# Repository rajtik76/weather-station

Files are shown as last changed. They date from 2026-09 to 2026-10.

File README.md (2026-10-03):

# Weather forecast station






Can a balcony weather station forecast its own next six hours better than
assuming nothing changes? A small model, trained on eight years of Czech
Hydrometeorological Institute (ČHMÚ) records, forecasts temperature and the
chance of rain one to six hours ahead from the station's own readings alone.
Every forecast is scored against what the station then measured, and the
front page sets the last 30 days' verdict beside the next six hours.

The bar to clear is persistence: the temperature stays as it is. The target
is not the air temperature a weather service forecasts but what this sensor
will read, and it is no professional sensor: on clear mornings the sun heats
its shield and the reading runs more than 10 °C high. A forecast for Plzeň
knows nothing of that, so it is no yardstick here. The model has to learn
this balcony, morning sun included, and the score shows how far the station
correction gets it: every forecast is also scored as the base model gave it,
before the correction.

The verdict is given for six hours ahead, with every shorter horizon beside
it, in three numbers over the last 30 days:

- **skill** - how much smaller the forecast's miss was than persistence's; below zero the forecast did worse
- **mean miss** - in °C, beside persistence's
- **in range** - how often the reading landed inside the forecast range; the range is drawn to hold 80 %, so less means too narrow

Until a day of forecasts has come true, the verdict says it is too early.

Running at [weather.rajtik.com](https://weather.rajtik.com).

## Architecture

```
SHT4x    --I2C--+
VEML7700 --I2C--+
BMP280   --I2C--+--> ESP32 --HTTPS--> Laravel API --> PostgreSQL
INMP441  --I2S--+                       |    |
                                        |  forecast service (Python)
                                   Livewire pages
```

- SHT4x (temperature, humidity) and VEML7700 (light) outside in a passive radiation shield, BMP280 (pressure) indoors, INMP441 microphone in the shield
- Readings every 30 s, folded into ten-minute windows and uploaded to the API
- Rain is detected from the microphone spectrum
- A Python service forecasts after every upload from the station's last 56 hours, with a station correction fitted daily on the last 60 days

## Known limitations

- Sensor reads more than 10 °C above air temperature for an hour or two on clear mornings (sun on the east-facing balcony, shield only partly helps); accepted, the forecast is scored against these same readings
- VEML7700 sits behind the shield's louvers: the shape of the day is real, the lux do not compare with a station in the open
- Rain thresholds come from one rain (checked against the ČHMÚ gauge 3.5 km away) and belong to this mounting; drizzle too fine to drip is not heard

## Run it

Needs PHP 8.4, Node 24 and Docker.

```
docker compose up -d              # PostgreSQL, with a second database for the tests
composer setup                    # install, .env, app key, migrate, build assets
php artisan migrate:fresh --seed  # a month of sample data; wipes the local database
composer dev                      # server, queue worker, logs, vite
```

## Documentation

- [`docs/development.md`](docs/development.md) - layout, configuration, tests, deploying
- [`docs/api.md`](docs/api.md) - ingest endpoint and storage
- [`docs/scoring.md`](docs/scoring.md) - how the forecast is scored
- [`firmware/README.md`](firmware/README.md) - wiring, protocol, hardware notes; [`firmware/CHANGELOG.md`](firmware/CHANGELOG.md)
- [`forecast/README.md`](forecast/README.md) - model and service; [`forecast/CHANGELOG.md`](forecast/CHANGELOG.md)
- `docs/hardware/kicad/` - KiCad projects of the station and the shield hub

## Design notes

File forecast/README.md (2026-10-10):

# Forecast

Temperature, humidity and pressure 1 to 6 hours ahead, and the chance of rain within those hours, from the station's own readings alone (no neighbouring stations, no numerical weather model, no radar at forecast time). Model history: [`CHANGELOG.md`](CHANGELOG.md).

## How it works

### Training data

- ČHMÚ open data (CC BY 4.0, credited in the site footer and on the forecast page): 10-minute records of the professional ("20000" series) stations, 2018 to 2025, the 32 below 700 m; about 1.7 million hourly examples
- Measures temperature, humidity, station pressure, plus precipitation (training label only)

### Inputs

`features.py`, shared by training and the service:

- Current temperature and humidity, and their distance from the dew point
- Change of temperature, humidity and pressure over 1, 3, 6, 12, 24, 48 h
- Pressure position in its two-day swing
- Unsettledness of the last 3 h: jitter of temperature and humidity, whether the pressure fall is speeding up
- Rain in the last 1 h and 3 h
- Solar time of day, day of the year
- Pressure only as a change (its level encodes elevation)
- Jitter computed on readings rounded to ČHMÚ's resolution

### Models

`train.py`: scikit-learn `HistGradientBoosting`, per horizon.

- Temperature, humidity, pressure: three quantile models (10th, 50th, 90th percentile of the change); the range should hold 4 readings in 5
- Rain: classifier for at least 0.1 mm within the next n hours
- Rain inputs hidden on 30 % of training rows (the balcony may have no rain source)
- `nest_rain()` in `forecast.py` caps the 1 h rain chance by the 2 h one (alone it gave 50-100 % on dry balcony days while longer horizons said 1-10 %)

### Station correction

`correction.py`; `POST /correction` fits it, Laravel caches the answer for a day and sends it back with every forecast.

- The service forecasts the station's recent history and compares it with what was measured
- Per variable and horizon, a ridge regression of the error on solar time and on the errors just verified
- Range widened or narrowed to hold 80 % of the station's readings
- Solar time as bins: 20 minutes from 5 to 12 h, an hour elsewhere
- Applies to temperature and humidity; correcting pressure scored worse
- The answer also carries the forecast before the correction (`base`)

### Light experiment

`sun_correction.py` (light-v5) learns the base model's misses on the balcony by day, `sky_gate.py` (light-v6) scales light-v5's shift by the sky the VEML7700 reads, `trees.py` carries the fitted models as plain numbers; `POST /light-correction` fits both once a day, `POST /light-forecast` issues both. Both enter the model race that picks the shown temperature per part of the day ([`docs/scoring.md`](../docs/scoring.md#model-race)).

- Per horizon a gradient-boosting model of the base forecast's miss with an absolute loss (the median miss, as the page scores the mean absolute miss)
- Sun on the shield from the temperature swing within each 10-minute window (`temperature_max - temperature_min`, smoothed over 30 min, peak of the hour, slow mean); reported since the shield went up, so every day from `since` on teaches, also those before the VEML7700
- Also the sun's position at issue and at the target (on the east facade or not), the change of the last 1 and 3 h, the base model's own change and its misses verified now (1 h ahead and the same horizon)
- Night stays the base forecast: sun lower than 3° below the horizon at issue and at the target
- Band: the base band moved with the median, widened to hold 4 readings in 5 by misses of models that did not see that day (four folds by local day)
- light-v5 takes no illuminance: with a week of light it helped some days and hurt others; a window without light is forecast too
- light-v6: a sky score per daylight window (sun above 8°), the illuminance over the brightest reading at the same UTC clock slot in the 14 days before the issue's local day; the state at issue is the mean score of the last hour in daylight, of the daylight in the last 24 h otherwise, overcast below 0.45, clear above 0.8
- light-v6 per horizon and state: a factor, the shift-weighted median of the miss over light-v5's out-of-fold shift (0 to 1.5, from 40 training rows); an unknown state or one without a factor keeps light-v5; its band is widened by its own out-of-fold misses

### Service

`serve.py`: stateless, no database.

- After every upload (`App\Jobs\ForecastWeather`), Laravel sends the last 56 hours and the cached correction; the answer is stored in `forecasts`
- Once a day Laravel sends the last 60 days to `POST /correction`, with `since` from `FORECAST_HISTORY_SINCE` if set (shield went up 16 September 2026, production learns from the 17th); a `409` for a stale correction refits it at once
- Page shows temperature and rain; humidity and pressure stay in the row
- Last 30 days of forecasts are scored as shown and before the correction, on the same hours, against persistence ([`docs/scoring.md`](../docs/scoring.md))

## Results

Scored on 2025 at four ČHMÚ stations the models never saw (Plzeň-Mikulka, Cheb, Kuchařovice, Pardubice). Mean absolute error, model median / persistence:

| Ahead | Temperature | Humidity | Pressure |
| ----- | --- | --- | --- |
| 1 h | 0.50 / 0.82 °C | 2.7 / 3.6 %  | 0.19 / 0.30 hPa |
| 3 h | 0.94 / 2.09 °C | 4.7 / 8.5 %  | 0.44 / 0.77 hPa |
| 6 h | 1.38 / 3.66 °C | 6.4 / 14.4 % | 0.85 / 1.36 hPa |

- 10-90 % range held the truth 76-81 % of the time
- Rain Brier score vs climatological rate: 0.039 / 0.068 at 1 h, 0.103 / 0.148 at 6 h
- Rain onset (still dry): ROC AUC 0.86 at 1 h, 0.79 at 6 h
- Training on 2018-2020 or 2022-2024 scored the same on 2025

Balcony, correction fitted up to 18 September 2026, scored 19 to 24 September (two weeks of record, will move):

| 6 h ahead | Without correction | With correction |
| --- | --- | --- |
| Temperature | 2.51 °C | 1.82 °C |
| Humidity | 9.7 % | 7.0 % |
| Temperature range coverage | 57 % | 74 % |

Bins vs two harmonics, walked forward day by day, fitted only on readings from 17 September (after the shield), scored 20 to 26 September:

| Case | Bins | Harmonics | No correction |
| --- | --- | --- | --- |
| Temperature 1 h ahead | 0.89 °C | 0.99 °C | 0.92 °C |
| 6 to 11 h, 2 h ahead | 1.74 °C | 2.25 °C | |
| 6 to 11 h, 3 h ahead | 2.03 °C | 2.45 °C | |
| 22 September (shade morning), 3 h ahead | 1.55 °C | 2.82 °C | 0.90 °C |

## Limitations

- A single station sees weather only once it arrives: on 24 September 2026 rain began at 06:20, forecasts issued before gave 1-4 % (air still fairly dry, pressure falling moderately, front invisible from the balcony)
- The correction made that morning worse: it learnt the sun warms the shield after sunrise, the morning was overcast; from temperature alone it cannot tell the two kinds of morning apart
- Sunny mornings are where the correction pays (halves misses of 3-5 °C)

## Running it

Python 3.14 and [uv](https://docs.astral.sh/uv/); run from this directory (`data/` and `models/` are gitignored).

```
uv run fetch_chmi.py download   # ~15 000 CSVs, 3 GB, into data/raw; resumable
uv run fetch_chmi.py build      # one parquet per station, 170 MB, + data/stations.csv
uv run train.py                 # ~22 minutes on an M4, writes models/forecast.joblib
uv run evaluate_balcony.py      # scores it on data/balcony.csv, rain from Mikulka
uv run serve.py                 # the service on :8000
```

- `evaluate_balcony.py` needs `data/balcony.csv` with columns `timestamp,t,h,p` (Unix seconds, °C, %, hPa station pressure) exported from the production database; rain labels (stand-in for the microphone detector) come from the ČHMÚ gauge at Plzeň-Mikulka, 3.5 km away
- Service env: `MODEL_PATH` (default `models/forecast.joblib`), `HOST`, `PORT`; reloads the model when the file changes
- Laravel reaches it through `FORECAST_URL`; unset, no forecasts

### The service's contract

```
POST /correction
{"longitude": 13.40, "since": 1789596000,
 "readings": [{"timestamp": 1790000000, "temperature": 9.7,
               "humidity": 76.0, "pressure": 976.6, "rain": null}, ...]}
```

- Up to a year of readings: °C, %, station pressure in hPa, rain in mm per ten minutes (null or absent without a source)
- `since` optional: the correction learns only from readings from then on; base models still read all (they need 48 h behind every forecast, as do the errors the correction takes as inputs)

```
{"model": "2026-09-24T08:40:43.136429+00:00", "correction": 3,
 "targets": {"T_1h": {"intercept": 0.41,
                      "coefficients": {"solar_0": -0.12, ..., "error_same": 0.3, "error_1h": 0.25},
                      "widen": 0.08}, ...}}
```

- One target per corrected variable and horizon; fewer, or none, while the history is short (3 days) or never verified
- Plain numbers: the ridge regression's intercept and weights by input name, and how far the range is widened (negative: narrowed)

```
POST /forecast
{"longitude": 13.40, "correction": {...},
 "readings": [{"timestamp": 1790000000, ...}, ...]}
```

- Readings as above; 54 h before the latest suffice (48 h behind the forecast issued 6 h earlier, whose verified error the correction reads), Laravel sends 56
- `correction` optional: the `POST /correction` answer as received; without it the forecast is the base models'
- A correction fitted for another model or correction version gets 409; malformed requests get 422 with the reason

```
{"issued_at": 1790000000, "model": "2026-09-24T08:40:43.136429+00:00",
 "corrected": true, "correction": 3,
 "horizons": [{"hours": 1,
               "temperature": {"low": 12.4, "mid": 13.84, "high": 15.56},
               "humidity": {...}, "pressure": {...},
               "rain_probability": 0.023,
               "base": {"temperature": {"low": 12.1, "mid": 13.46, "high": 15.9},
                        "humidity": {...}, "rain_probability": 0.023}}, ...]}
```

- `issued_at`: the latest reading's ten-minute window
- `model`: the bundle's `trained_at`
- `corrected`: whether the correction sent covered every corrected target
- `correction`: version of the correction logic (`CORRECTION_VERSION` in `correction.py`, raised with every change, logged in the changelog)
- `base`: forecast before the correction, for the two corrected variables; pressure is not corrected, so its forecast is the one above
- `base.rain_probability`: the classifier's value before `nest_rain()` capped the first hour; a capped run shows as `data->0->'base'->>'rain_probability'` above `data->0->>'rain_probability'`
- `GET /health` answers `{"status": "ok", "model": ..., "correction": 3, "experiment": "light-v6"}`

```
POST /base
{"longitude": 13.40, "since": 1789400000, "readings": [...]}
```

Base forecast for every reading from `since` on, for forecasts stored before the service returned `base`:

```
{"model": "2026-09-24T08:40:43.136429+00:00",
 "forecasts": [{"issued_at": 1789400000,
                "horizons": [{"hours": 1, "temperature": {...},
                              "humidity": {...}, "rain_probability": 0.023}, ...]}, ...]}
```

- Base models look 48 h back only, so the answer equals what the service gave at the time if readings start that far before `since`; the correction is not recomputed
- `php artisan forecast:backfill-base` asks a week at a time, with three days of readings before it, and fills in only forecasts made by the model now running

```
POST /light-correction
{"longitude": 13.40, "since": 1789596000,
 "readings": [{"timestamp": 1790000000, "temperature": 9.7, "humidity": 76.0, "pressure": 976.6,
               "temperature_min": 9.62, "temperature_max": 9.81,
               "illuminance": 1830.5, "received_at": 1790000031}, ...]}
```

- Readings as for `/correction` plus `temperature_min` and `temperature_max` (°C within the window, null without) and `illuminance` (lx, null without); `received_at`, which Laravel sends too, is ignored
- `since` optional: only forecasts issued from then on teach it (Laravel sends `FORECAST_HISTORY_SINCE`)

```
{"model": "2026-09-24T08:40:43.136429+00:00", "version": "light-v6",
 "fit": {"day": "2026-10-07",
         "horizons": [{"hours": 1, "baseline": 0.31, "widen": 0.42,
                       "trees": [[[6, 0.83, 0, 1, 2], [0.12], [-0.05]], ...]}, ...],
         "gate": {"envelope": [null, ..., 2431.5, ...],
                  "horizons": [{"hours": 1, "factors": {"day:overcast": 0.24, "night:clear": 1.5}, "widen": 0.44}, ...]}}}
```

- `day`: the newest reading's local day
- One entry per horizon with 300 verified daytime rows; fewer or none while the history is short
- `trees`: the fitted model as plain numbers, per tree its nodes; a split `[input, threshold, missing values go left (0/1), left, right]` (inputs in `sun_correction.INPUTS` order, threshold null for +inf), a leaf `[value]`; the miss is `baseline` plus one leaf per tree
- `gate`: light-v6 on top; `envelope` the brightest illuminance per UTC 10-minute clock slot (144) in the 14 days before `day`, null where never lit; per horizon its factors by state (`day:` or `night:` and `overcast`, `mixed` or `clear`) and its own `widen`
- About 200 KB; Laravel caches it per sensor, local day and `since`, and fits it on readings through the newest of the window it issues from

```
POST /light-forecast
{"longitude": 13.40, "experiment": {...}, "readings": [...]}
```

- `experiment`: the `/light-correction` answer as received; another model or version, or a fit for another local day than the newest reading's, gets 409; a malformed tree or gate 422
- Readings as for `/light-correction`; 54 h suffice, as for `/forecast`

```
{"issued_at": 1790000000, "model": "2026-09-24T08:40:43.136429+00:00", "version": "light-v6",
 "versions": {"light-v5": [{"hours": 1, "temperature": {"low": 12.4, "mid": 13.6, "high": 15.1}}, ...],
              "light-v6": [{"hours": 1, "temperature": {"low": 11.9, "mid": 12.7, "high": 14.0}}, ...]}}
```

- Per version one horizon per fitted horizon; at night the base band; `version` names the newest
- `php artisan forecast:backfill-light <Y-m-d>` replays both calls for forecasts stored without the version `/health` reports (`experiment`), each from the readings the server held at the time; an older version is replaced where the current one is issued, a forecast it cannot issue keeps the older one; every version answered joins the race candidates

## Deploying

- `Dockerfile` builds from this directory: dependencies into a virtualenv with uv, then Python, the virtualenv and the eight service files; about 550 MB
- The model is not in the image: mounted at `/models`
- No domain or published port; Laravel reaches it on the internal Docker network
- New model: train, check `evaluate_balcony.py`, copy `forecast.joblib` over the mounted one, add a changelog entry
- First deploy of a service that returns `base`: run `php artisan forecast:backfill-base` in the app container before a new model goes on (only the model that made a forecast can recompute its base)

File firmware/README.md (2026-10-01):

# Firmware

ESP32-WROOM-32, mains powered, never sleeps.

- Every 30 s: temperature and humidity (SHT4x), pressure (BMP280), illuminance (VEML7700)
- Continuously: INMP441 microphone
- Ten-minute windows: mean, min, max per channel plus noise levels and third-octave spectrum
- Each closed window is uploaded to `POST /api/v1/measurement` over HTTPS; failures stay buffered on flash
- Station is inspectable over the LAN without a cable

```
SHT4x    --I2C--+
VEML7700 --I2C--+
BMP280   --I2C--+--> ESP32-WROOM-32 --HTTPS--> Laravel API
INMP441  --I2S--+     core 0: noise   |    \
                      core 1: the rest |     HTTP on the LAN: status and log
                                       |
                         window buffer on the flash, 144 entries (a day)
```

## Hardware

Schematics (KiCad exports): [station](../docs/hardware/kicad/WeatherStation/WeatherStation_schematic.svg), [base board](../docs/hardware/kicad/BaseBoard/BaseBoard_schematic.svg), [shield hub](../docs/hardware/kicad/ShieldHub/ShieldHub_schematic.svg).

### Cable

4 m FTP (four twisted pairs) from ESP32 board to shield hub. ESP32 side: Dupont pins. Hub side: soldered in column 5 of the perfboard.

| Pair | Wire | Signal | ESP32 side | Hub side |
| ---- | --- | --- | --- | --- |
| 1 | blue | SD | GPIO33 (D33) | R5 47 Ω → mic SD  |
| 1 | white-blue | GND | GND | GND, C2 |
| 2 | orange | SDA | GPIO21 (D21) | SHT4x, VEML7700 |
| 2 | white-orange | 3V3 | 3V3 | C2, all three VCC |
| 3 | white-green  | SCL | GPIO22 (D22) | SHT4x, VEML7700 |
| 3 | green | GND | GND | GND |
| 4 | white-brown  | SCK | GPIO26 via R3 47 Ω | mic SCK |
| 4 | brown | WS | GPIO25 via R4 47 Ω | mic WS |

- Both grounds connect at both ends (with one open, the SHT4x on the old hub dropped about one reading in seven while WiFi was on)
- I2C lines share a pair with a supply or ground; I2S clocks have their own pair, so SCK never runs next to SDA or SCL
- Clocks still couple into I2C over 4 m, hence they stop for every sensor read (see _Noise_)
- Foil cut back at both ends; drain grounded only on the base board's cable header
- I2C pins come from the board variant via `SDA` / `SCL` (GPIO21 / GPIO22 on the DevKit); I2S pins in `noise.h`
- INMP441 `L/R` strapped to GND (left slot)
- I2C bus at 20 kHz (`I2C_CLOCK_HZ`)
- Serial: CP2102 bridge, port `/dev/cu.usbserial-*`; plugging it in resets the board

### Shield hub

[`docs/hardware/kicad/ShieldHub`](../docs/hardware/kicad/ShieldHub): [schematic](../docs/hardware/kicad/ShieldHub/ShieldHub_schematic.svg), perfboard as a board, [3D preview](../docs/hardware/kicad/ShieldHub/ShieldHub_3D_preview.png). Every KiCad file is generated; edit the script, not KiCad (edits are lost on the next run).

```
cd docs/hardware/kicad/ShieldHub
python3 generate_schematic.py        # schematic and symbols, plain Python
/Applications/KiCad/KiCad.app/Contents/Frameworks/Python.framework/Versions/3.9/bin/python3 generate_board.py
python generate_models.py            # STEP models, needs CadQuery
python generate_assembly.py          # perforated 3D assembly, needs CadQuery
```

- B.Cu tracks: tinned wire on the solder side; F.Cu tracks: insulated wires on the component side
- A wire end sits in a free hole (a via in KiCad) and is soldered from below to the run next to it; nothing is soldered on the component side
- Check changes with KiCad DRC and schematic parity

### Base board

[`docs/hardware/kicad/BaseBoard`](../docs/hardware/kicad/BaseBoard): 60 x 80 mm perfboard, DevKit and BMP280 in female headers. [Schematic](../docs/hardware/kicad/BaseBoard/BaseBoard_schematic.svg), [3D preview](../docs/hardware/kicad/BaseBoard/BaseBoard_3D_preview.png), [solder side](../docs/hardware/kicad/BaseBoard/BaseBoard_3D_solder_side.png).

- `layout.py` holds parts and runs for both generators; refuses a short or a split net
- A run is a 0 Ω link on the component side plus solder bridges between neighbouring pads below

```
cd docs/hardware/kicad/BaseBoard
python generate_models.py            # BMP280, 0 Ω links, rings and bridges; needs CadQuery
python3 generate_schematic.py        # schematic and symbols, plain Python
/Applications/KiCad/KiCad.app/Contents/Frameworks/Python.framework/Versions/3.9/bin/python3 generate_board.py
```

## Build

- Arduino IDE, board _ESP32 Dev Module_, ESP32 core 3.x
- Libraries: `Adafruit BMP280 Library`, `Adafruit SHT4x Library`, `ArduinoJson` v7; FFT is esp-dsp (in the core)
- _Partition Scheme_: _Minimal SPIFFS (1.9MB APP with OTA/128KB SPIFFS)_ - OTA needs two app slots, image ~1.2 MB; the 128 kB filesystem holds the 13 kB window buffer and two 32 kB logs
- Changing the partition scheme wipes the filesystem (buffered backlog is lost once)
- Everything else at defaults

```
cp secrets.example.h secrets.h
```

- Fill in device name, WiFi, token, OTA password; set `API_URL` in `weather_station.ino`
- `BEARER_TOKEN` must match `SENSOR_API_TOKEN` in the server's `.env`; `secrets.h` is gitignored

Two WiFi networks:

- Station lives on the primary; moves to the backup after 1 min without association or 3 consecutive failed uploads while associated
- On the backup it retries the primary every hour with an empty buffer
- Empty `BACKUP_WIFI_SSID` = single network

```
arduino-cli compile --fqbn esp32:esp32:esp32:PartitionScheme=min_spiffs weather_station
```

### Versions

- `FIRMWARE_VERSION` in `weather_station.ino` is bumped with every build that goes on a board: fix = patch, feature = minor, new board or protocol = major
- The commit is tagged `fw/v<version>` (the app uses `v<version>`)
- The board reports the version in every upload (`station_reports`)
- History in [`CHANGELOG.md`](CHANGELOG.md); field-to-server-release map in [`docs/api.md`](../docs/api.md#firmware-and-server-versions)

## Updating over the air

- Port 3232, announced over mDNS; the IDE lists `weather-station` under _Port_
- Password `OTA_PASSWORD`; empty = OTA off

```
arduino-cli upload --fqbn esp32:esp32:esp32:PartitionScheme=min_spiffs --port weather-station.local weather_station
```

- The IP works when mDNS is slow
- Image lands in the other app slot and the board restarts from it
- The window being filled is closed into the buffer first; the noise task is paused, so the window in which the update lands loses its noise
- No rollback: a boot-looping build (v2.1.0 did) stays in the slot the bootloader picks, only the cable recovers it; compile before uploading

## Looking at the station

Plain HTTP on the LAN, no authentication, read-only: `http://weather-station.local/` (mDNS) or the IP.

| Path | What it is |
| --- | --- |
| `/` | What the station is doing, as text |
| `/status` | The same as JSON, plus last POST's code and time |
| `/log` | The last 8 kB of log from RAM, readings included |
| `/log/flash` | The log on the flash: everything but readings, survives a restart |

`/status` and the `station` object in every upload carry:

- Firmware version, board (`ARDUINO_BOARD`), last boot reason, uptime, free heap and its minimum
- SSID, IP, RSSI, which network, number of switches
- Windows in the buffer, uploads failed in a row
- Clock drift: `clock_step_ms` (last SNTP correction, positive when the clock ran slow), `clock_step_over_s` (how long the drift accumulated), `clock_step_max_ms` (largest since boot), `clock_synced_at` (epoch of last sync)
- Drift fields are zero until the first re-sync after boot (the first answer steps the clock from 1970 or from a clock of unknown age)

## Protocol

Version 4. Fixed-point integers, converted at reading time. One entry per ten-minute window: V2 fields, `illuminance` with extremes when the VEML7700 gave data, `noise` object when the microphone did. Units and ranges: [`docs/api.md`](../docs/api.md).

```json
{
    "sensor_name": "sensor-001",
    "protocol_version": 4,
    "measurements": [
        {
            "timestamp": 1757000000,
            "temperature": 2602,
            "temperature_min": 2588,
            "temperature_max": 2631,
            "humidity": 4871,
            "humidity_min": 4820,
            "humidity_max": 4910,
            "pressure": 97389,
            "pressure_min": 97381,
            "pressure_max": 97396,
            "samples": 20,
            "illuminance": 1123000,
            "illuminance_min": 980000,
            "illuminance_max": 1310000,
            "noise": {
                "seconds": 600,
                "laeq": 5562,
                "lamax": 5898,
                "la10": 5797,
                "la90": 5284,
                "bands": [3120, 3305, ...26 in all...]
            }
        }
    ]
}
```

- A `station` object (see above) goes beside `measurements`; stored apart from readings, optional
- Bare field = mean over the window, rounded to nearest; `_min` / `_max` = lowest / highest reading; the server refuses min above mean or max below it
- Window = epoch slot: `timestamp / 600` names it. The stamp is the last reading's.
- Pressure is station pressure (not reduced); the server reduces it to sea level for display (`App\ValueObject\SeaLevelPressure`, height `StationSite::ALTITUDE_METRES`)

## Behaviour

### Clock

- Nothing is read until NTP has answered once; the clock counts through a lost link
- SNTP re-syncs hourly while online, also after a software restart (the clock lives in the RTC)
- The sketch replaces `sntp_sync_time()` to read the clock before stepping it; the difference is the reported drift
- The replacement runs on its own task and only notes numbers; the loop writes the log line

### Buffer and upload

- Closed windows wait in a buffer, oldest first, 144 deep; in RAM, mirrored to a flash file after every change; any restart loses only the window being filled
- Batches of 16 straight after a window closes; stops at the first failure, retries a minute later
- A batch leaves the buffer only after a 2xx; the server upserts on `(sensor, timestamp)`, so a resend is harmless
- Readings outside the protocol ranges are dropped before they reach the window (one bad value would get the whole batch rejected)

### Stall guards

- Task watchdog restarts the board when the loop has not run for 2 min
- Loop restarts the board after an hour with a backlog and no successful upload, checked between windows
- Next boot logs the reset reason; the flash log rotates at 32 kB, two files deep

### Sensors

- A reading needs both SHT4x and BMP280; if either fails the reading is dropped
- SHT4x: high precision, heater off; `sht4xBegin()` spends the first read (it failed more often than not)
- BMP280: forced mode, oversampling, IIR filter off
- VEML7700: optional; a failed or saturated read drops only the light; a window without light goes out without `illuminance`
- VEML7700 is driven through its registers (`veml7700.cpp`); five ranges from gain 2 at 100 ms (0.034 lx per count) to gain 1/8 at 25 ms (141 klx); one step per read towards the light, neighbours differ by at most 4x; no non-linearity correction
- Lux are the shield's (behind the louvers), not comparable with a station in the open
- Microphone SCK and WS stop for every sensor read (`noiseHush()`); running, they made the VEML7700 miss about every other transfer; clocks also use the weakest GPIO driver

### TLS and WiFi

- `ca_certs.h` pins ISRG Root X1 and ISRG Root YR (not the leaf; Root YR survives the cross-sign being dropped); validated against the system clock
- WiFi stays associated; the loop nudges every 30 s, hands the other network a turn after a minute, and lists what the radio hears when the first association fails
- RSSI: about -70 dBm comfortable, -80 marginal, past -85 a TLS upload will not survive

## Noise

`noise.cpp`: task pinned to core 0 (below WiFi and lwIP); core 1 runs the loop.

- I2S 16 kHz, 32-bit slots, left channel; 24-bit sample read as `int32_t`, shifted `>> 8`, scaled to full scale 1 as `float`
- 2048-point FFT (esp-dsp), Hann windows overlapping by half: a frame every 64 ms, 7.8 Hz bins (4096 points left the TLS upload 2 kB of heap)
- Bin power corrected for the INMP441 high-pass (+10 dB at 25 Hz, +1.6 dB at 100 Hz, flat from 500 Hz); bins below 20 Hz left out
- 26 base-10 third-octave bands (25 Hz to 8 kHz, unweighted) and one A-weighted total (IEC 61672)
- Calibration: dB SPL = dBFS + 120 (-26 dBFS at 94 dB SPL) plus `MIC_OFFSET_DB` = -15 (phone SLM)
- Per window: `laeq` energy mean of all frames, `lamax` loudest second (LAeq,1s), `la10` / `la90` levels exceeded 10 % / 90 % of the seconds, `seconds` count; bands are energy means
- Slots follow the wall clock; nothing counted before the clock is set or for 3 s after the mic starts
- A frame with no signal (SD stuck) counts as silent and is left out: a dead mic sends windows without `noise`
- Every sensor read parks the task and disables I2S (costs about 0.5 s of noise per reading)
- The ~40 kB of buffers go back to the heap before every upload and are reallocated after (held, mbedTLS could not allocate); the window misses those seconds, so `seconds` often reads a little under 600
- A resume with no memory is retried every minute from the loop (`NOISE_RETRY_MS`)
- A mic that does not start at boot gives its buffers back; the station runs without noise until the next restart

Limits:

- Nyquist is 8 kHz: the 8 kHz band (7.1 - 8.9 kHz) sees only its lower half and reads low; the 25 - 40 Hz bands get one bin each
- Rain is detected from these bands by `App\ValueObject\RainDetector` (roof drops ring the shield's plastic at 1 kHz and fill the top band); thresholds belong to this mounting, recheck against a few rains after moving the mic or shield

## Sketches

- `weather_station` - the station
- `sensors_check` - diagnostics: I2C scan, then a line every 2 s with BMP280, SHT4x, VEML7700 and INMP441 level; clocks stopped around I2C reads as in the station; retries a missing sensor

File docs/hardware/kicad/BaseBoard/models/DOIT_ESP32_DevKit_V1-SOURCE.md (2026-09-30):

# DOIT ESP32 DevKit V1 (30 pin, micro-USB) STEP model

`DOIT_ESP32_DevKit_V1_30pin_microUSB.step.gz` is `USB-micro_esp32_30pin+PIN.step`
by Josselin Hefti, gzipped unchanged. KiCad reads `.step.gz` directly.

- Source: https://www.printables.com/model/1362332-esp32-devkit-v1-board-30-pin
- License: Creative Commons - Public Domain

The model's origin sits off the pins: the EN pin is at (-0.64, 42.83), the
pin rows are 25.40 mm apart and the black header spacer ends 4.17 mm under the
PCB top. The footprint offsets it by (0.64, -42.83, 12.67) so the spacer rests
on the 8.5 mm female headers.

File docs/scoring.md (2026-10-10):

# Forecast scoring

The headline verdict (skill, mean miss, in range over 30 days) is in the [README](../README.md).

## Stored

- One forecast after every upload (the next upload replaces a failed one): the server sends the forecast service the last 56 hours with the station correction and stores the answer
- The correction is fitted on the last 60 days once a day and cached per sensor; a correction the service calls stale (another model or correction version, `409`) is refitted at once
- Temperature as a range 1 to 6 h ahead, chance of rain, and the same temperature from the base model (before the station correction)
- `App\Queries\ForecastAccuracy` reads and pairs, `App\ValueObject\ForecastScore` does the arithmetic, `ModelName` names a model

## Weather model

Stored for later use, neither scored nor shown: it forecasts air temperature, the station forecasts its own reading with the sun on the shield.

- `ForecastWeather` fetches DWD ICON (`icon_seamless`) from Open-Meteo for the station's coordinates and elevation with every forecast and stores it as `nwp.temperature` (°C) under each horizon
- Hourly values interpolated to the middle of the scored ten-minute window
- Skipped for a forecast issued more than 20 min ago (late batch): a run fetched now would know more than the forecast did
- A failed fetch is reported; the forecast is stored without it

## Forecast page

- Same scoring for every hour ahead
- Per horizon, skill by day: as shown vs base model on the same hours; the gap is what the station has taught the shown forecast
- Day a new model or correction version took over is marked
- Range width
- Mean rain chance given when it rained and when it did not
- Chart by hour of the day of how much warmer or colder the station read than forecast (morning sun on the shield reads warmer), shown and base on the same forecasts, for yesterday, the last 7 days or the last 30 days, by the hour each forecast was for
- Its default, today, draws the readings since local midnight against the forecast issued one horizon before each ten-minute slot, the shown range as a band; it grows with every reload

## Light experiment

Two more temperature forecasts learnt from the station alone ([`forecast/README.md`](../forecast/README.md#light-experiment)): light-v5 moves the base model by its misses on the balcony by day, with the sun on the shield read from the temperature swing within each window; light-v6 scales that move by the sky the VEML7700 reads. Both enter the model race below.

- After the forecast is stored, `ForecastWeather` asks `POST /light-forecast`; every version it answers goes into `candidates` under each horizon, the newest also into `experiment` (`version`, `temperature`)
- Its fit comes from `POST /light-correction` once per local day of the newest reading, from the 60 days through that reading with `since` from `FORECAST_HISTORY_SINCE`, and is cached per sensor
- A failure is reported and pauses the experiment for an hour; the forecast is already stored and the race picks among the entrants it has
- The forecast page adds the newest version as one more line to skill by day, range width and the hour-of-day chart, scored on its own forecasts; tooltips give each line's count. By hour it shows only in a period whose first forecast already carried it, today always
- `php artisan forecast:backfill-light <Y-m-d>` replays it on forecasts stored without its current version, from the readings the server held when each was issued (`created_at`); unlike the weather model, nothing later leaks in. An older version is replaced where the current one is issued, a forecast it cannot issue keeps the older one; the page scores the latest version only. A forecast stored before the race gets its shown band as the `correction` candidate
- Sample data: `LightForecastSeeder` adds a synthetic `demo-light-v1` curve, flagged `synthetic`; the page labels it a preview

## Model race

Picks the shown temperature for each part of the day from the model that has forecast it best lately.

- Entrants: `base`, `correction` (the station correction, shown before the race), `light-v5` and `light-v6` (`App\ValueObject\RaceEntrants`); the stored forecast keeps every entrant's band, `base` under `base`, the others under `candidates`
- Points per local day and part of the day the target falls in, night 22-6 h, morning 6-12 h, afternoon and evening 12-22 h (`App\Enums\RaceBlock`): each entrant's mean absolute miss of its median in °C, on the targets every entrant forecast (`App\Queries\ModelRace`)
- Standings: points summed over the 14 local days before today, worked out once a day after midnight and cached per sensor (`CachedModelRace`); the fewest lead, a tie goes to the simpler model in the order above (at night light-v5 and light-v6 answer the base band), a part of the day without points keeps the correction
- Every new forecast shows per horizon the band of the leader of its target's part of the day, or of the next entrant when the leader did not answer it; `shown_by` names it. Humidity and rain stay the correction's
- A stored forecast keeps what it showed; the race never re-picks history
- The forecast page charts every entrant's points by day for the chosen part of the day, lists the standings, and names each hour of the current forecast by the model shown on the horizon nearest to it

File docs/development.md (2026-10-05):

# Development

## The site

A station is whatever uploads under a `sensor_name`; the first upload registers it in `sensors`, a description can be added by hand. A header picker switches stations once there are two.

Three Livewire pages on the base `StationPage`. Window and station are in the URL.

| Page | Path | Shows |
| --- | --- | --- |
| Overview | `/` | current readings per channel with the last 24 h, next six hours with the verdict, the board's report, approximate location; the only self-refreshing page |
| Charts | `/charts` | temperature, humidity (dew point on request), sea-level pressure; last week by default, min-max band, whole-record strip to drag a window up to a month; bucket width follows the span |
| Forecast | `/forecast` | how the model works, the forecast now, the verdict by horizon, [scoring](scoring.md) |

Charts, when the data exists:

- Noise strips: A-weighted level with LA90 to LA10 band and loudest second; third-octave spectrum waterfall with a rain icon over columns where rain was heard
- Light strip: lux in the shield, log scale
- Events from `station_events` (entered by hand) marked on the charts
- Below: the three newest windows as stored and the station's full report

Rain is detected by `App\ValueObject\RainDetector` per ten-minute window: ring around 1 kHz plus a loud top of the spectrum.

## Layout

| Path | Contents |
| --- | --- |
| `firmware/` | Arduino sketches; [`README`](../firmware/README.md), [`CHANGELOG`](../firmware/CHANGELOG.md) |
| `forecast/` | ČHMÚ fetching, training, scoring, the service; [`README`](../forecast/README.md), [`CHANGELOG`](../forecast/CHANGELOG.md) |
| `app/Http/` | Ingest endpoint, form request, bearer token middleware |
| `app/Enums/` | `ProtocolVersion` (payload version to decoder), bucket widths per span |
| `app/ValueObject/`  | Per-version payload decoding; calculations for the pages: sea-level pressure, dew point, rain, forecast scores, number format |
| `app/Models/` | Sensors, measurements, station reports, forecasts, events |
| `app/Queries/` | Everything pages and jobs read: chart buckets, scoring, newest forecast and report, the one client of the forecast service, the station correction cached for a day |
| `app/Jobs/` | `ForecastWeather` (asks the service after every upload, stores the answer and the light experiment); `BackfillForecastBase` (`php artisan forecast:backfill-base`), `BackfillLightExperiment` (`php artisan forecast:backfill-light`) |
| `app/Livewire/` | The three pages; views and partials in `resources/views/livewire/` |
| `database/seeders/` | A month of two stations (first: last three days with noise and two showers, last day with light), two weeks of forecasts each |
| `docs/` | [API contract](api.md); KiCad projects in `docs/hardware/kicad/` |
| `docker/` | nginx, PHP-FPM, supervisord config for the production image; init script for the local test database |

## Running it

Needs PHP 8.4, Node 24 and Docker. No paid Flux components, no `auth.json`.

```
docker compose up -d   # PostgreSQL 18 on 5432, with a second database for the tests
composer setup         # install, .env, app key, migrate, build assets
php artisan migrate:fresh --seed   # a month of sample data; wipes the local database
composer dev           # server, queue worker, logs, vite
composer test
composer review        # rector, phpstan, js, forecast (uv) and php tests
```

PostgreSQL everywhere (same image as production); the charts average buckets in SQL only PostgreSQL speaks.

### `.env`

| Variable | Meaning |
| --- | --- |
| `SENSOR_API_TOKEN` | Bearer token the firmware sends; the endpoint denies everything while empty |
| `SENSOR_HEARTBEAT_URL` | Optional; requested after each stored batch (push monitor) |
| `FORECAST_URL` | Optional; forecast service address, locally `http://127.0.0.1:8000` after `uv run serve.py` in `forecast/`; unset, no forecasts |
| `FORECAST_HISTORY_SINCE` | Local date such as `2026-09-17`; earlier readings stay out of the station correction; invalid value is reported and ignored |
| `FORECAST_NWP_URL` | Numerical weather model stored with every forecast (not scored), default Open-Meteo `https://api.open-meteo.com/v1/forecast`; empty disables it (the tests do) |

### Sample data

- `MeasurementSeeder`: a month of two stations at the reporting interval; first station has noise for its last three days (two showers) and light for the last one, the second has neither
- `ForecastSeeder`: a forecast on every ten-minute slot of each station's last two weeks; synthetic, shaped like the service's answer (improving correction, a new model taking over five days back)
- `LightForecastSeeder` (local and testing only): a synthetic light experiment on forecasts issued while the station had light
- The forecast and accuracy panel show without the service running

## Deploying

- `Dockerfile`: one image, assets on Node, dependencies on Composer, nginx + PHP-FPM + Laravel scheduler under supervisord on port 8080
- Entrypoint caches config, routes and views at start; it does not run migrations - do that in the deploy
- Forecast service: second image from `forecast/`, model mounted; no public address, point `FORECAST_URL` at it on the internal network; see [`forecast/README.md`](../forecast/README.md#deploying)
- Once, after both are deployed: `php artisan forecast:backfill-base`

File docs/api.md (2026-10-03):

# Ingest API

Validated by `App\Http\Requests\StoreMeasurementRequest`, stored by `App\Http\Controllers\StoreMeasurementController`. Firmware side: [firmware README](../firmware/README.md#protocol).

## Endpoint

```
POST /api/v1/measurement
Authorization: Bearer <SENSOR_API_TOKEN>
Content-Type: application/json
```

- One token for all stations, compared in constant time against `SENSOR_API_TOKEN`
- Empty token on the server denies everyone
- 10 requests per minute per IP

## Request

```json
{
    "sensor_name": "sensor-001",
    "protocol_version": 2,
    "measurements": [
        {
            "timestamp": 1757000000,
            "temperature": 2602,
            "temperature_min": 2588,
            "temperature_max": 2631,
            "humidity": 4871,
            "humidity_min": 4820,
            "humidity_max": 4910,
            "pressure": 97389,
            "pressure_min": 97381,
            "pressure_max": 97396,
            "samples": 20
        }
    ],
    "station": {
        "firmware": "2.3.0",
        "board": "ESP32C3_DEV",
        "reset_reason": "power on",
        "uptime": 86400,
        "heap_free": 183000,
        "heap_min": 149000,
        "ssid": "home",
        "ip": "192.168.0.200",
        "rssi": -61,
        "wifi_network": 0,
        "wifi_switches": 0,
        "buffered": 0,
        "upload_failures": 0,
        "clock_step_ms": 412,
        "clock_step_over_s": 3600,
        "clock_step_max_ms": 412,
        "clock_synced_at": 1757000000
    }
}
```

| Field | Rule |
| --- | --- |
| `sensor_name` | string, 3 to 50 characters; registers the station on first use |
| `protocol_version` | `1` to `4`; decides which fields each measurement carries |
| `measurements` | 1 to 500 entries |

`timestamp`: UTC Unix seconds, 1 to 4294967295. All values are integers: hundredths of °C and %, Pa.

| Field | V1  | V2+ | Range |
| --- | --- | --- | --- |
| `temperature` | yes | yes | -4000 .. 8500 |
| `humidity` | yes | yes | 0 .. 10000 |
| `pressure` | yes | yes | 30000 .. 110000 |
| `temperature_min`, `temperature_max` | | yes | as above |
| `humidity_min`, `humidity_max` | | yes | as above |
| `pressure_min`, `pressure_max` | | yes | as above |
| `samples` | | yes | 1 .. 65535 |

- **V1** - one reading per entry; stands in as its own minimum and maximum
- **V2** - ten-minute window of half-minute readings: bare field is the mean, `_min` / `_max` the extremes, `samples` the count; `_min` above the mean or `_max` below it fails validation
- **V3** - V2 plus optional `noise` object per measurement
- **V4** - V3 plus optional illuminance

### Illuminance (V4)

- VEML7700 on the shield hub; present only when the window had at least one reading, then all three fields are required
- Integers in hundredths of a lux, 0 .. 15000000; same min/mean/max rule as other channels
- Measured inside the radiation shield: shape is the signal, absolute lux are not comparable with another station
- Drawn on a log axis

| Field | Meaning |
| --- | --- |
| `illuminance` | mean over the window |
| `illuminance_min`, `illuminance_max` | lowest and highest reading in it |

### `noise` object (V3+)

Optional as a whole; once present every field is required.

```json
"noise": {
    "seconds": 600,
    "laeq": 4312,
    "lamax": 6120,
    "la10": 4705,
    "la90": 3890,
    "bands": [2210, 2345, 2098, 1876, 1654, 1432, 1298, 1187, 1065, 987, 912, 856, 798, 745, 698, 654, 612, 578, 542, 498, 456, 412, 378, 342, 298, 254]
}
```

| Field | Type | Range |
| --- | --- | --- |
| `seconds` | integer, one-second levels in the window | 1 .. 600 |
| `laeq` | integer, hundredths of dB(A), energy mean over the window | 0 .. 15000, `laeq <= lamax` |
| `lamax` | integer, hundredths of dB(A), loudest one-second Leq | 0 .. 15000 |
| `la10` | integer, hundredths of dB(A), level exceeded 10 % of the seconds | 0 .. 15000, `la10 <= lamax` |
| `la90` | integer, hundredths of dB(A), level exceeded 90 % of the seconds | 0 .. 15000, `la90 <= la10`  |
| `bands` | 26 integers, hundredths of dB, unweighted (Z) | each 0 .. 15000 |

`bands` is the third-octave spectrum at 25, 31.5, 40, 50, 63, 80, 100, 125, 160, 200, 250, 315, 400, 500, 630, 800, 1000, 1250, 1600, 2000, 2500, 3150, 4000, 5000, 6300, 8000 Hz.

### `station` object

Optional as a whole; once present every field is required. Keys not in the rules are dropped before storing.

| Field | Type |
| --- | --- |
| `firmware` | string, up to 32 |
| `board` | string, up to 40 |
| `reset_reason` | string, up to 40 |
| `uptime`, `heap_free`, `heap_min`, `wifi_switches`, `buffered`, `upload_failures` | integer, 0 or more |
| `ssid`, `ip` | string or null |
| `rssi` | integer, -120 .. 0 |
| `wifi_network` | `0` primary, `1` backup |

Exceptions, so older builds keep uploading:

- `clock_step_ms`, `clock_step_over_s`, `clock_step_max_ms`, `clock_synced_at` (firmware 2.2+): all four or none; a partial set is refused
- `board` (`ARDUINO_BOARD`: `ESP32C3_DEV`, `DFROBOT_FIREBEETLE_2_ESP32C6`, `ESP32_DEV`, firmware 2.3+) may be left out

### Firmware and server versions

Firmware is tagged `fw/v<version>` ([`firmware/CHANGELOG.md`](../firmware/CHANGELOG.md)), the app `v<version>`.

| Payload | Firmware from | Server from |
| --- | --- | --- |
| `protocol_version` 1 | 1.0.0 | v1.0.0 |
| `protocol_version` 2, windows with extremes | 2.0.0 | v2.0.0 |
| `station` object | 2.1.0 | v2.1.0 |
| `station.clock_step_*`, `station.clock_synced_at` | 2.2.0 | v2.2.0 |
| `station.board` | 2.3.0 | v3.0.0 |
| `protocol_version` 3, `noise` per window | 3.0.0 | v3.0.1 |
| `protocol_version` 4, illuminance per window | 4.0.0 | v4.0.0 |

- A server older than the row refuses a V2, V3 or V4 batch (unknown `protocol_version`) and ignores an unknown `station` or `noise` object; every later field is optional
- A firmware older than the row does not send the field; the dashboard leaves the row out
- `board` is absent from the payload before 2.3; the changelog is the only record of the hardware

## Response

| Status | When |
| --- | --- |
| `201`  | Stored. Body `{"stored": n}`, rows written or replaced. |
| `401`  | Missing or wrong bearer token. Body `{"message": "Unauthenticated."}`. |
| `422`  | Validation failed. Laravel's `{"message": ..., "errors": {field: [...]}}`. |
| `429`  | More than 10 requests in a minute. |

- Validation is all or nothing: one invalid entry rejects the batch, nothing is stored
- After storing, once the response has gone out: `SENSOR_HEARTBEAT_URL` is requested if set
- Same for `FORECAST_URL`: every upload asks the forecast service for a forecast ([scoring](scoring.md#stored)); a failure is logged and ignored, the next upload retries

## Storage

| Table | Holds |
| --- | --- |
| `sensors` | stations; created by the first upload under a new `sensor_name`, description added by hand |
| `measurements` | one row per window per station |
| `station_reports` | one `jsonb` row per batch, tied to the sensor; newest shown under the payload tail |
| `forecasts` | one row per forecast service run |

- `measurements`: `sensor_id`, `timestamp`, `protocol_version`, `jsonb` blob with the version's fields as the firmware sent them
- `(sensor_id, timestamp)` is unique; the endpoint upserts (new blob and version replace the old), so a resent batch never duplicates
- Conversion to °C, % and hPa and the sea-level pressure reduction (`StationSite::ALTITUDE_METRES`) happen on read
- `protocol_version` is its own column; `App\Enums\ProtocolVersion` maps a version to its value object in `App\ValueObject\`; a new format is a new case and class
- `forecasts`: `sensor_id`, `issued_at` (ten-minute window of the starting reading, unique per sensor), `model` (the model's `trained_at`, see [`forecast/CHANGELOG.md`](../forecast/CHANGELOG.md)), whether the station correction applied, six horizons as `jsonb` in °C, % and hPa; service contract in [`forecast/README.md`](../forecast/README.md#the-services-contract)

## Aggregation

- The dashboard queries PostgreSQL for buckets: ten minutes up to a day, half an hour up to a week, an hour up to a month
- One `generate_series` query per render; mean of the means, extreme of the extremes (the band behind each line)
- Tests and local development need PostgreSQL; the SQL has no portable form

## Retention

- Nothing is pruned or rolled up
- One row per ten-minute window: 144 a day per station, about 53 000 a year
- `station_reports` grows at the same rate and is the first candidate for pruning

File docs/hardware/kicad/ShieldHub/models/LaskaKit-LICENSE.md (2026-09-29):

The TAPR Open Hardware License
Version 1.0 (May 25, 2007)
Copyright 2007 TAPR - http://www.tapr.org/OHL

PREAMBLE

Open Hardware is a thing - a physical artifact, either electrical or
mechanical - whose design information is available to, and usable by,
the public in a way that allows anyone to make, modify, distribute, and
use that thing. In this preface, design information is called
"documentation" and things created from it are called "products."

The TAPR Open Hardware License ("OHL") agreement provides a legal
framework for Open Hardware projects. It may be used for any kind of
product, be it a hammer or a computer motherboard, and is TAPR's
contribution to the community; anyone may use the OHL for their Open
Hardware project.

Like the GNU General Public License, the OHL is designed to guarantee
your freedom to share and to create. It forbids anyone who receives
rights under the OHL to deny any other licensee those same rights to
copy, modify, and distribute documentation, and to make, use and
distribute products based on that documentation.

Unlike the GPL, the OHL is not primarily a copyright license. While
copyright protects documentation from unauthorized copying, modification,
and distribution, it has little to do with your right to make, distribute,
or use a product based on that documentation. For better or worse, patents
play a significant role in those activities. Although it does not prohibit
anyone from patenting inventions embodied in an Open Hardware design, and
of course cannot prevent a third party from enforcing their patent rights,
those who benefit from an OHL design may not bring lawsuits claiming that
design infringes their patents or other intellectual property.

The OHL addresses unique issues involved in the creation of tangible,
physical things, but does not cover software, firmware, or code loaded
into programmable devices. A copyright-oriented license such as the GPL
better suits these creations.

How can you use the OHL, or a design based upon it? While the terms and
conditions below take precedence over this preamble, here is a summary:

- You may modify the documentation and make products based upon it.

- You may use products for any legal purpose without limitation.

- You may distribute unmodified documentation, but you must include the
  complete package as you received it.

- You may distribute products you make to third parties, if you either
  include the documentation on which the product is based, or make it
  available without charge for at least three years to anyone who requests
  it.

- You may distribute modified documentation or products based on it, if
  you:
    - License your modifications under the OHL.
    - Include those modifications, following the requirements stated
      below.
    - Attempt to send the modified documentation by email to any of the
      developers who have provided their email address. This is a good
      faith obligation - if the email fails, you need do nothing more
      and may go on with your distribution.

- If you create a design that you want to license under the OHL, you
  should:
    - Include this document in a file named LICENSE (with the appropriate
      extension) that is included in the documentation package.
    - If the file format allows, include a notice like "Licensed under
      the TAPR Open Hardware License (www.tapr.org/OHL)" in each
      documentation file. While not required, you should also include
      this notice on printed circuit board artwork and the product
      itself; if space is limited the notice can be shortened or
      abbreviated.
    - Include a copyright notice in each file and on printed circuit
      board artwork.
    - If you wish to be notified of modifications that others may make,
      include your email address in a file named "CONTRIB.TXT" or
      something similar.

- Any time the OHL requires you to make documentation available to
  others, you must include all the materials you received from the
  upstream licensors. In addition, if you have modified the
  documentation:
    - You must identify the modifications in a text file (preferably
      named "CHANGES.TXT") that you include with the documentation.
      That file must also include a statement like "These modifications
      are licensed under the TAPR Open Hardware License."
    - You must include any new files you created, including any
      manufacturing files (such as Gerber files) you create in the
      course of making products.
    - You must include both "before" and "after" versions of all files
      you modified.
    - You may include files in proprietary formats, but you must also
      include open format versions (such as Gerber, ASCII, Postscript,
      or PDF) if your tools can create them.

TERMS AND CONDITIONS

1.  Introduction
    1.1 This Agreement governs how you may use, copy, modify, and
    distribute Documentation, and how you may make, have made, and
    distribute Products based on that Documentation. As used in this
    Agreement, to "distribute" Documentation means to directly or indirectly
    make copies available to a third party, and to "distribute" Products
    means to directly or indirectly give, loan, sell or otherwise transfer
    them to a third party.

1.2 "Documentation" includes:
(a) schematic diagrams;
(b) circuit or circuit board layouts, including Gerber and other
data files used for manufacture;
(c) mechanical drawings, including CAD, CAM, and other data files
used for manufacture;
(d) flow charts and descriptive text; and
(e) other explanatory material.
Documentation may be in any tangible or intangible form of expression,
including but not limited to computer files in open or proprietary
formats and representations on paper, film, or other media.

1.3 "Products" include:
(a) circuit boards, mechanical assemblies, and other physical parts
and components;
(b) assembled or partially assembled units (including components
and subassemblies); and
(c) parts and components combined into kits intended for assembly
by others;
which are based in whole or in part on the Documentation.

1.4 This Agreement applies to any Documentation which contains a
notice stating it is subject to the TAPR Open Hardware License, and to
all Products based in whole or in part on that Documentation. If
Documentation is distributed in an archive (such as a "zip" file) which
includes this document, all files in that archive are subject to this
Agreement unless they are specifically excluded. Each person who
contributes content to the Documentation is referred to in this
Agreement as a "Licensor."

1.5 By (a) using, copying, modifying, or distributing the
Documentation, or (b) making or having Products made or distributing
them, you accept this Agreement, agree to comply with its terms, and
become a "Licensee." Any activity inconsistent with this Agreement will
automatically terminate your rights under it (including the immunities
from suit granted in Section 2), but the rights of others who have
received Documentation, or have obtained Products, directly or
indirectly from you will not be affected so long as they fully comply
with it themselves.

1.6 This Agreement does not apply to software, firmware, or code
loaded into programmable devices which may be used in conjunction with
Documentation or Products. Such software is subject to the license
terms established by its copyright holder(s).

2.  Patents
    2.1 Each Licensor grants you, every other Licensee, and every
    possessor or user of Products a perpetual, worldwide, and royalty-free
    immunity from suit under any patent, patent application, or other
    intellectual property right which he or she controls, to the extent
    necessary to make, have made, possess, use, and distribute Products.
    This immunity does not extend to infringement arising from modifications
    subsequently made by others.

2.2 If you make or have Products made, or distribute Documentation
that you have modified, you grant every Licensor, every other Licensee,
and every possessor or user of Products a perpetual, worldwide, and
royalty-free immunity from suit under any patent, patent application, or
other intellectual property right which you control, to the extent
necessary to make, have made, possess, use, and distribute Products.
This immunity does not extend to infringement arising from modifications
subsequently made by others.

2.3 To avoid doubt, providing Documentation to a third party for the
sole purpose of having that party make Products on your behalf is not
considered "distribution,"\" and a third party's act of making Products
solely on your behalf does not cause that party to grant the immunity
described in the preceding paragraph.

2.4 These grants of immunity are a material part of this Agreement,
and form a portion of the consideration given by each party to the
other. If any court judgment or legal agreement prevents you from
granting the immunity required by this Section, your rights under this
Agreement will terminate and you may no longer use, copy, modify or
distribute the Documentation, or make, have made, or distribute
Products.

3.  Modifications
    You may modify the Documentation, and those modifications will become
    part of the Documentation. They are subject to this Agreement, as are
    Products based in whole or in part on them. If you distribute the
    modified Documentation, or Products based in whole or in part upon it,
    you must email the modified Documentation in a form compliant with
    Section 4 to each Licensor who has provided an email address with the
    Documentation. Attempting to send the email completes your obligations
    under this Section and you need take no further action if any address
    fails.

4.  Distributing Documentation
    4.1 You may distribute unmodified copies of the Documentation in its
    entirety in any medium, provided that you retain all copyright and other
    notices (including references to this Agreement) included by each
    Licensor, and include an unaltered copy of this Agreement.
    4.2 You may distribute modified copies of the Documentation if you
    comply with all the requirements of the preceding paragraph and:
    (a) include a prominent notice in an ASCII or other open format
    file identifying those elements of the Documentation that you
    changed, and stating that the modifications are licensed under
    the terms of this Agreement;
    (b) include all new documentation files that you create, as well as
    both the original and modified versions of each file you change
    (files may be in your development tool's native file format,
    but if reasonably possible, you must also include open format,
    such as Gerber, ASCII, Postscript, or PDF, versions);
    (c) do not change the terms of this Agreement with respect to
    subsequent licensees; and
    (d) if you make or have Products made, include in the Documentation
    all elements reasonably required to permit others to make
    Products, including Gerber, CAD/CAM and other files used for
    manufacture.

5.  Making Products
    5.1 You may use the Documentation to make or have Products made,
    provided that each Product retains any notices included by the Licensor
    (including, but not limited to, copyright notices on circuit boards).
    5.2 You may distribute Products you make or have made, provided that
    you include with each unit a copy of the Documentation in a form
    consistent with Section 4. Alternatively, you may include either (i) an
    offer valid for at least three years to provide that Documentation, at
    no charge other than the reasonable cost of media and postage, to any
    person who requests it; or (ii) a URL where that Documentation may be
    downloaded, available for at least three years after you last distribute
    the Product.

6.  NEW LICENSE VERSIONS
    TAPR may publish updated versions of the OHL which retain the same
    general provisions as the present version, but differ in detail to
    address new problems or concerns, and carry a distinguishing version
    number. If the Documentation specifies a version number which applies
    to it and "any later version", you may choose either that version or any
    later version published by TAPR. If the Documentation does not specify
    a version number, you may choose any version ever published by TAPR.
    TAPR owns the copyright to the OHL, but grants permission to any person
    to copy, distribute, and use it in unmodified form.

7.  WARRANTY AND LIABILITY LIMITATIONS
    7.1 THE DOCUMENTATION IS PROVIDED ON AN"AS-IS" BASIS WITHOUT
    WARRANTY OF ANY KIND, TO THE EXTENT PERMITTED BY APPLICABLE LAW. ALL
    WARRANTIES, EXPRESS OR IMPLIED, INCLUDING BUT NOT LIMITED TO ANY
    WARRANTIES OF MERCHANTABILITY, FITNESS FOR A PARTICULAR PURPOSE, AND
    TITLE, ARE HEREBY EXPRESSLY DISCLAIMED.
    7.2 IN NO EVENT UNLESS REQUIRED BY APPLICABLE LAW WILL ANY LICENSOR
    BE LIABLE TO YOU OR ANY THIRD PARTY FOR ANY DIRECT, INDIRECT,
    INCIDENTAL, CONSEQUENTIAL, PUNITIVE, OR EXEMPLARY DAMAGES ARISING OUT OF
    THE USE OF, OR INABILITY TO USE, THE DOCUMENTATION OR PRODUCTS,
    INCLUDING BUT NOT LIMITED TO CLAIMS OF INTELLECTUAL PROPERTY
    INFRINGEMENT OR LOSS OF DATA, EVEN IF THAT PARTY HAS BEEN ADVISED OF THE
    POSSIBILITY OF SUCH DAMAGES.
    7.3 You agree that the foregoing limitations are reasonable due to
    the non-financial nature of the transaction represented by this
    Agreement, and acknowledge that were it not for these limitations, the
    Licensor(s) would not be willing to make the Documentation available to
    you.
    7.4 You agree to defend, indemnify, and hold each Licensor harmless
    from any claim brought by a third party alleging any defect in the
    design, manufacture, or operation of any Product which you make, have
    made, or distribute pursuant to this Agreement. ####

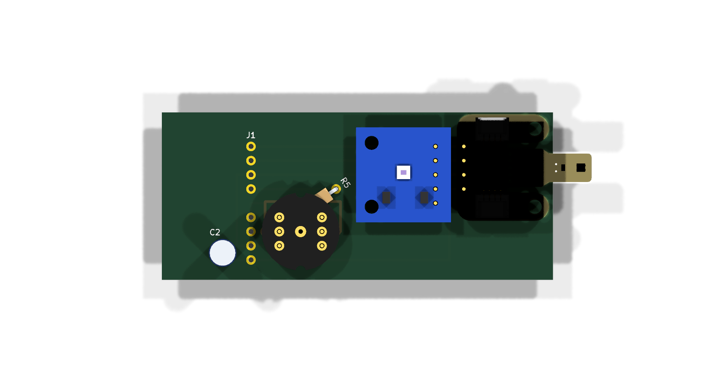
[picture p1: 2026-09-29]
docs/hardware/kicad/ShieldHub/ShieldHub_3D_preview.png

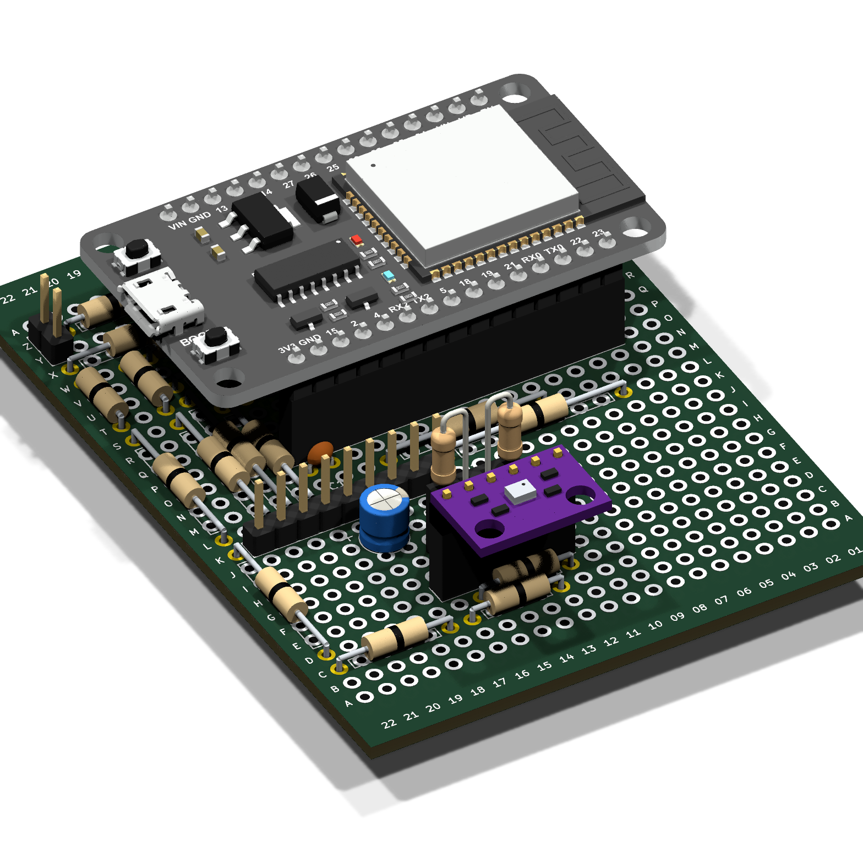
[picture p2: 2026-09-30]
docs/hardware/kicad/BaseBoard/BaseBoard_3D_preview.png

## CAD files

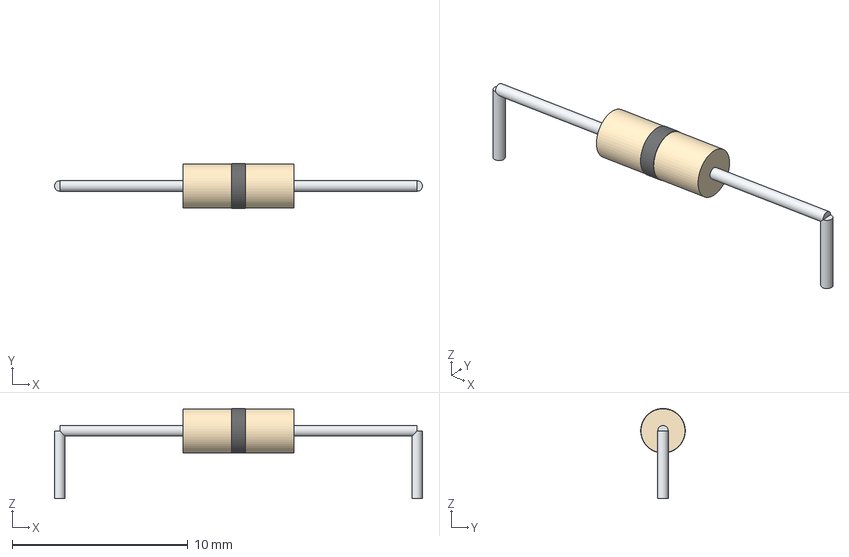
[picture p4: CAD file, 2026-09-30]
docs/hardware/kicad/BaseBoard/models/R_Jumper_P20.32.step
20.9 x 2.54 x 5.12 mm
zero_ohm_band
leads

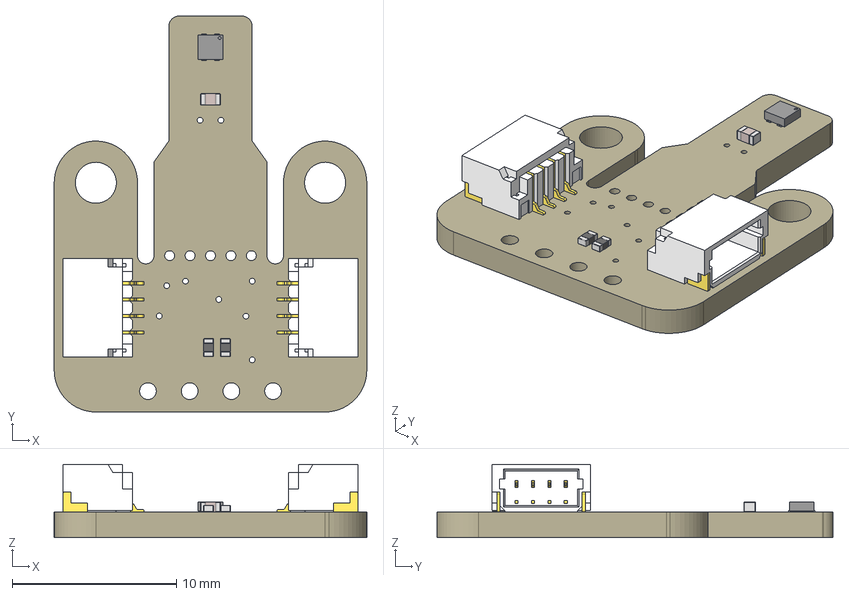
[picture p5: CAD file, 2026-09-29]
docs/hardware/kicad/ShieldHub/models/Temp-HumSensor_SHT45.step
19.1 x 24.1 x 4.47 mm
Board
LASKAKIT_HEART_4MM
LASKKIT_10MM_SILKSCREEN
USUP_4MM_SILKSCREEN x 2
1X04_1MM_RA x 2
ThermalPin
PinsArrayLR
C0402
R0402 x 2

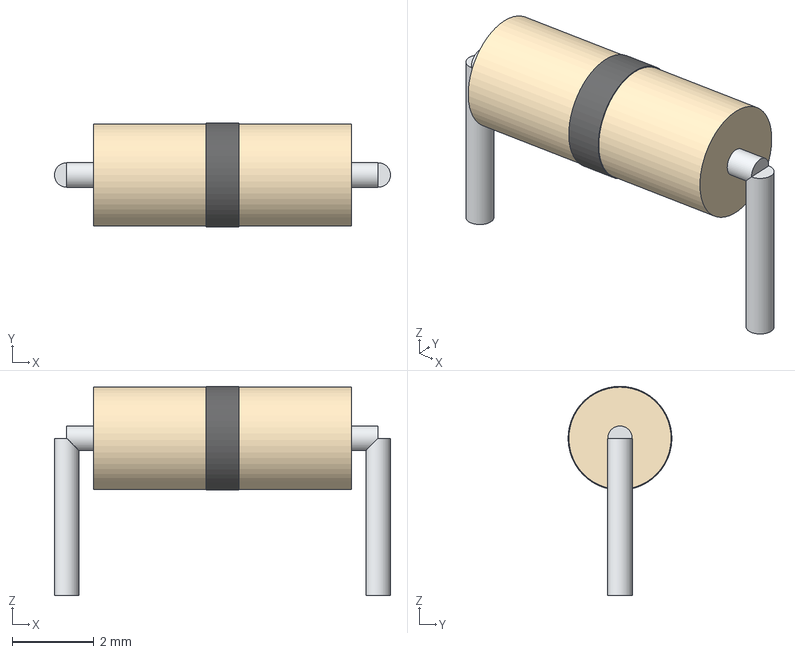
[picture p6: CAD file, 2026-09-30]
docs/hardware/kicad/BaseBoard/models/R_Jumper_P7.62.step
8.22 x 2.54 x 5.12 mm
zero_ohm_band
leads

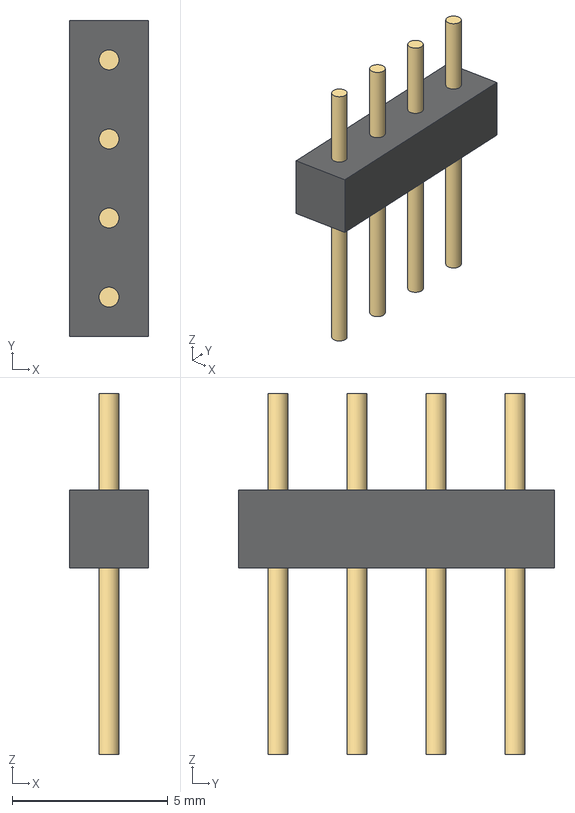
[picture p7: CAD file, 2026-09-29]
docs/hardware/kicad/ShieldHub/models/SHT45_pin_header.step
2.54 x 10.2 x 11.6 mm
header_spacer_0
header_pin_0
header_pin_1
header_pin_2
header_pin_3

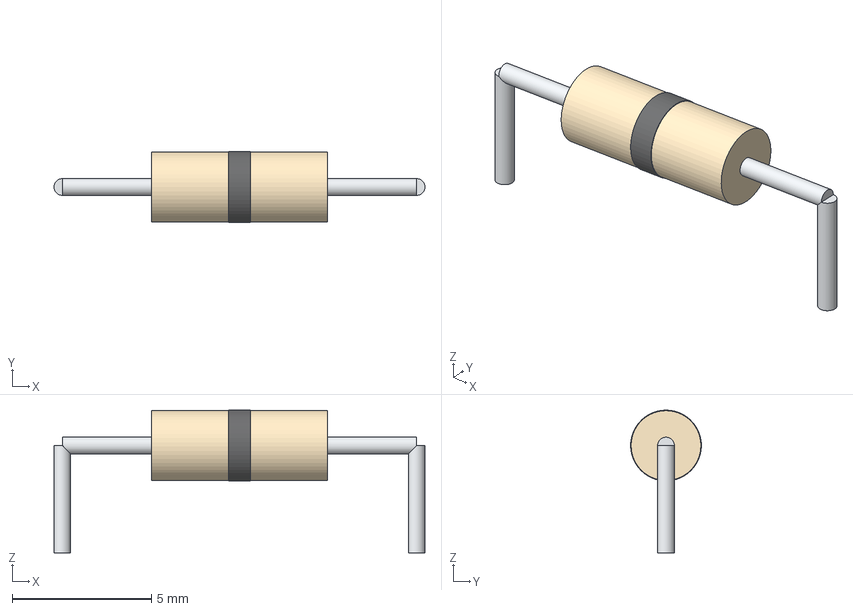
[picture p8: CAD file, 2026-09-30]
docs/hardware/kicad/BaseBoard/models/R_Jumper_P12.70.step
13.3 x 2.54 x 5.12 mm
zero_ohm_band
leads

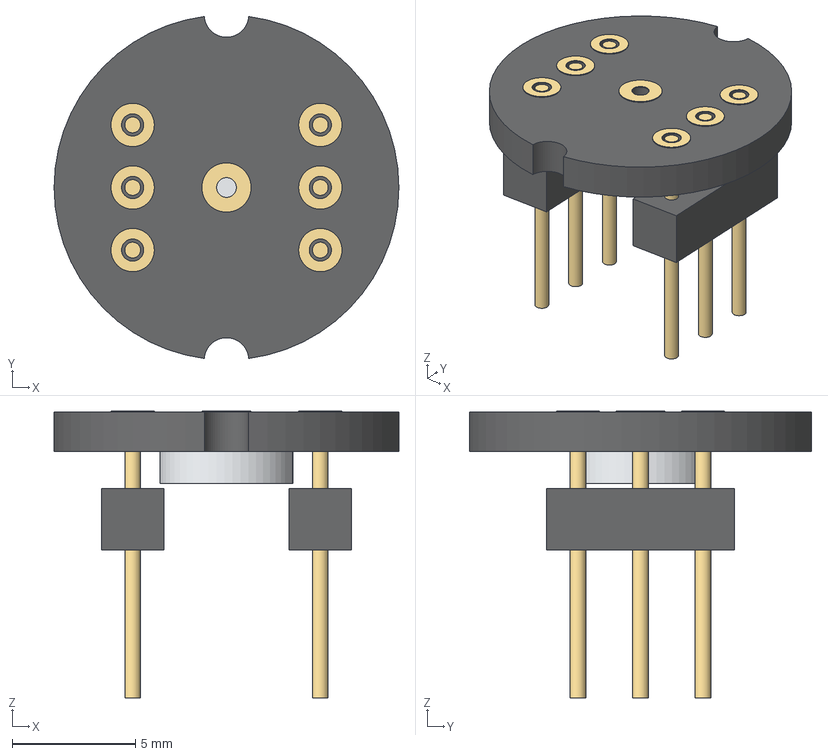
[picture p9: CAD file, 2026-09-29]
docs/hardware/kicad/ShieldHub/models/INMP441_Round_approx.step
14.0 x 13.9 x 11.6 mm
round_black_pcb
header_spacer_0
header_spacer_1
header_pin_0
header_pin_1
header_pin_2
header_pin_3
header_pin_4
header_pin_5
microphone_can
outward_sound_port
pad_ring_0
pad_ring_1
pad_ring_2
pad_ring_3
pad_ring_4
pad_ring_5

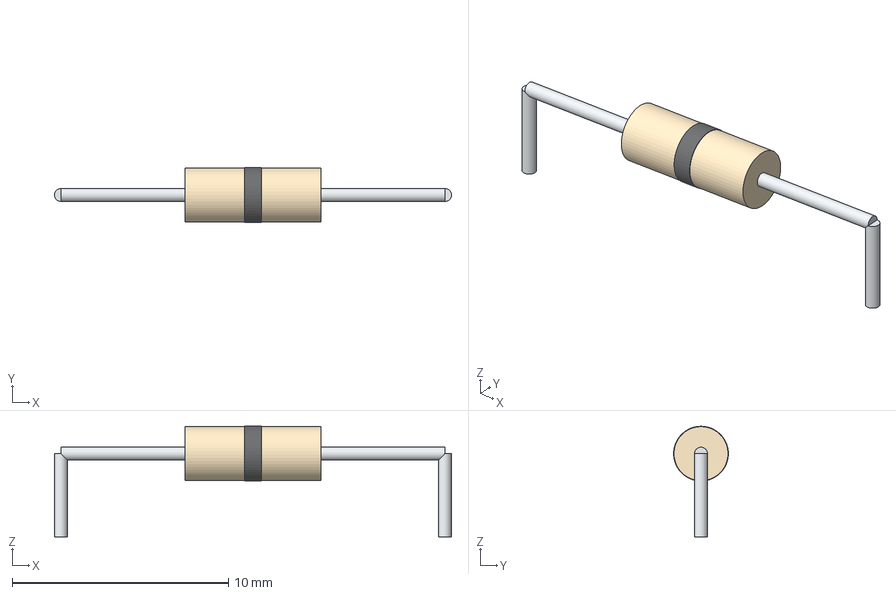
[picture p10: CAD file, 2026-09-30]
docs/hardware/kicad/BaseBoard/models/R_Jumper_P17.78.step
18.4 x 2.54 x 5.12 mm
zero_ohm_band
leads

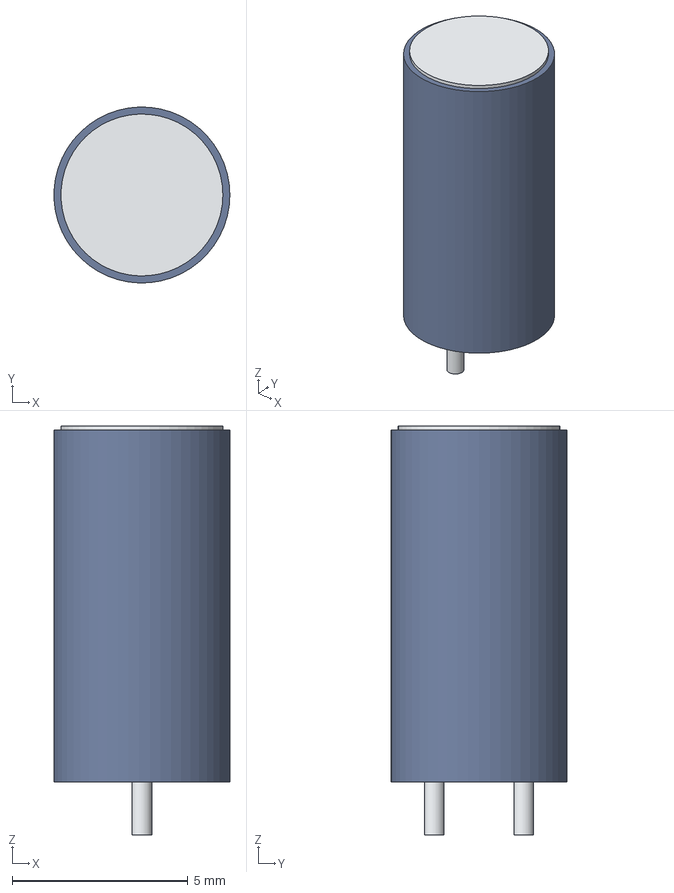
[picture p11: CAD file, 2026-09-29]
docs/hardware/kicad/ShieldHub/models/C2_10u_approx.step
5.00 x 5.00 x 11.6 mm
electrolytic_can
electrolytic_top
capacitor_lead_0
capacitor_lead_1

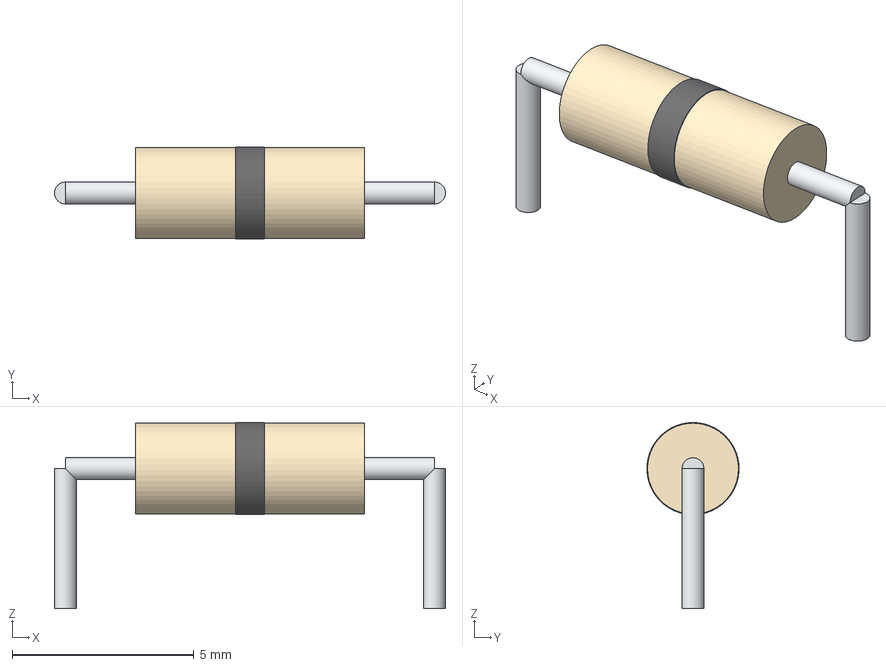
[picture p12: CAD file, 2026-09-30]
docs/hardware/kicad/BaseBoard/models/R_Jumper_P10.16.step
10.8 x 2.54 x 5.12 mm
zero_ohm_band
leads

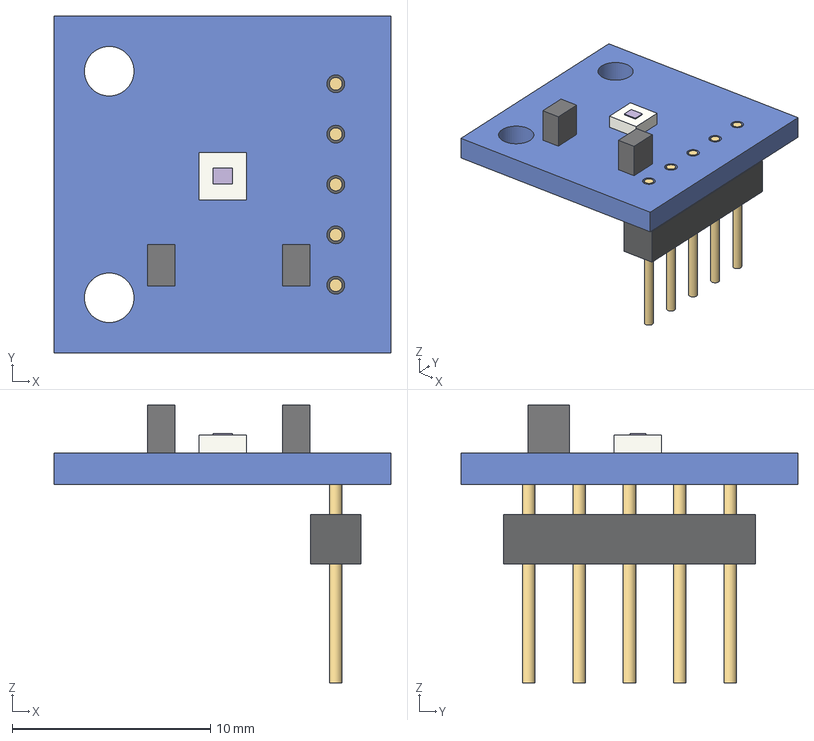
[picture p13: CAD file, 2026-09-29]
docs/hardware/kicad/ShieldHub/models/VEML7700_Techfun_approx.step
17.0 x 17.0 x 14.0 mm
blue_breakout_pcb
header_spacer_0
header_pin_0
header_pin_1
header_pin_2
header_pin_3
header_pin_4
light_sensor_housing
light_sensor_window
support_ic_0
support_ic_1

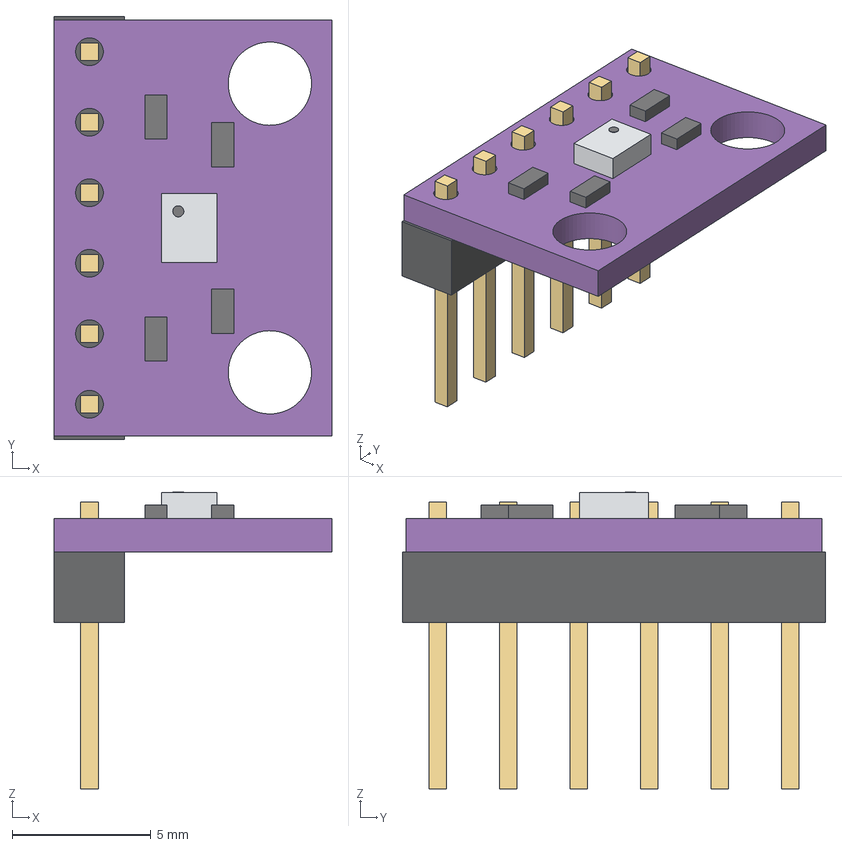
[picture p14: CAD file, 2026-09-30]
docs/hardware/kicad/BaseBoard/models/BMP280_Module_approx.step
10.0 x 15.2 x 10.7 mm
purple_breakout_pcb
header_spacer
header_pin_0
header_pin_1
header_pin_2
header_pin_3
header_pin_4
header_pin_5
bmp280_lid
bmp280_vent
passive_0
passive_1
passive_2
passive_3

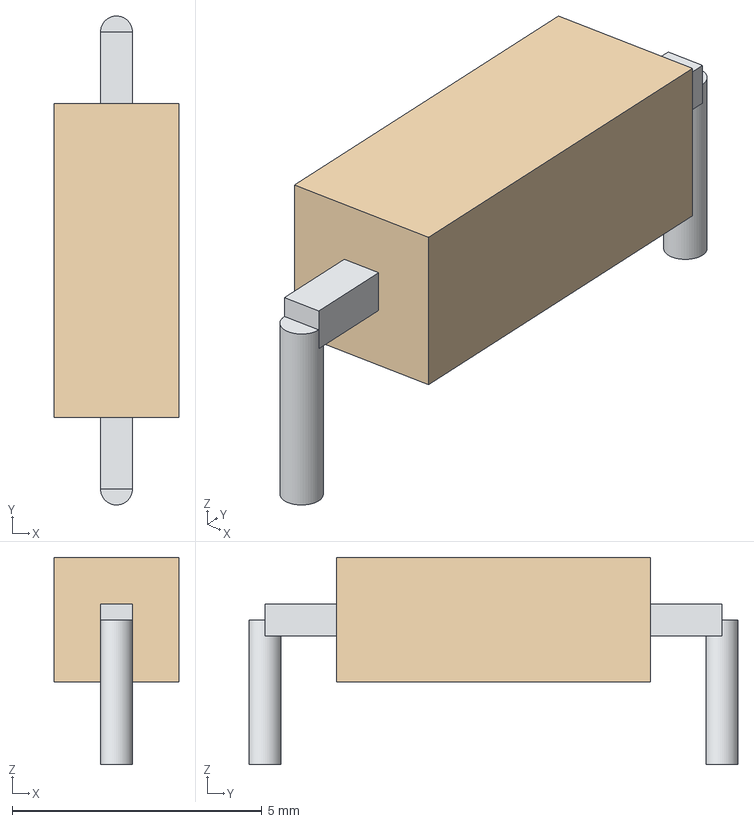
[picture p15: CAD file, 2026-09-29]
docs/hardware/kicad/ShieldHub/models/R5_47R_approx.step
2.50 x 9.80 x 4.15 mm
resistor_body
resistor_lead_0
resistor_lead_bend_0
resistor_lead_1
resistor_lead_bend_1

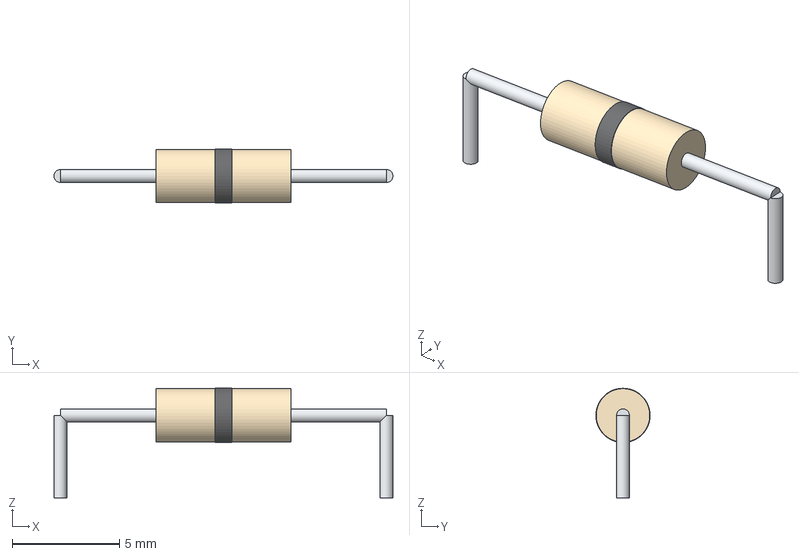
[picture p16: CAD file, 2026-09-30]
docs/hardware/kicad/BaseBoard/models/R_Jumper_P15.24.step
15.8 x 2.54 x 5.12 mm
zero_ohm_band
leads

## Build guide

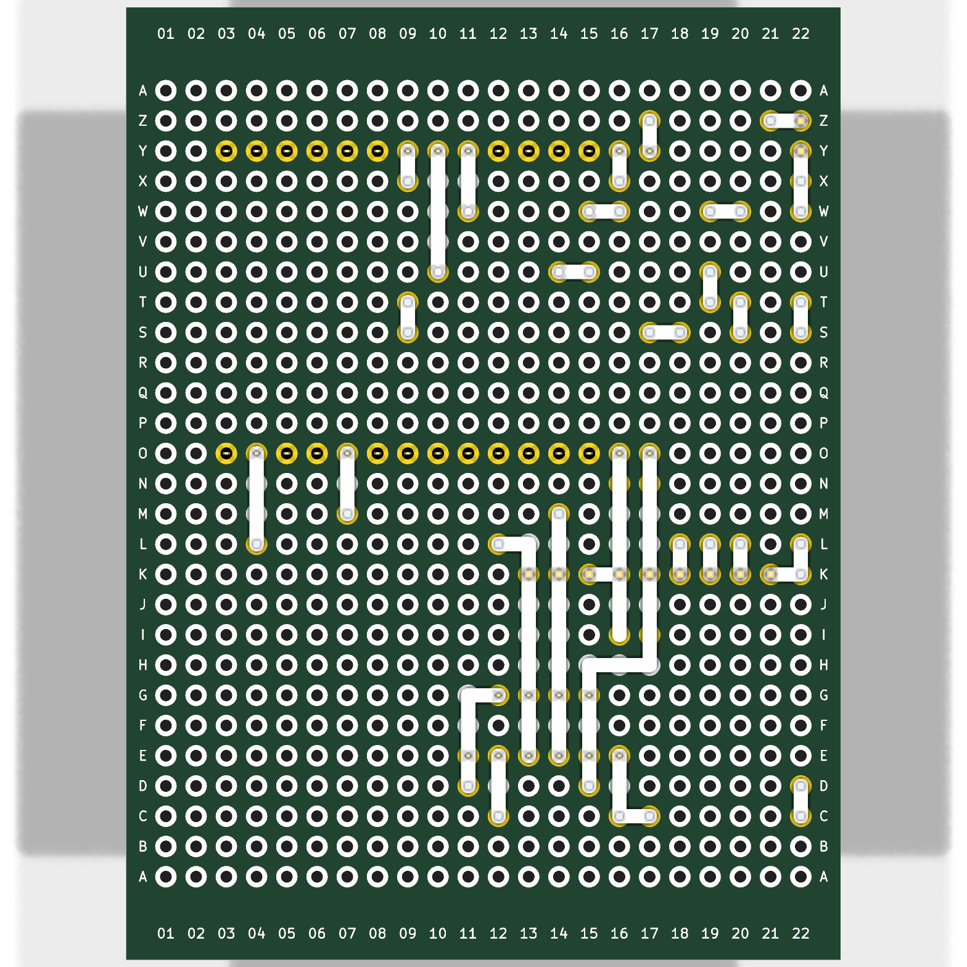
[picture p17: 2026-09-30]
docs/hardware/kicad/BaseBoard/BaseBoard_3D_solder_side.png

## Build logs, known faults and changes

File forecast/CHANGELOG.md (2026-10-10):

# Forecast model changelog

- One entry per model bundle on the server, headed by its `trained_at` (reported as `model`, stored in every `forecasts` row)
- `Data` = training data, `Server` = first app release whose service and dashboard read it
- Scores: 2025, held-out ČHMÚ stations ([README](README.md#results)), mean absolute error 6 h ahead vs persistence unless stated
- A change to the correction's logic (`correction.py`) gets an entry `Correction <n>` (`CORRECTION_VERSION`, reported as `correction`, stored per row; rows before it was kept are version 1); scores on the balcony, walked forward day by day

## Light experiment light-v6 - 2026-10-10

Model 2026-09-24T08:40:43Z · Server v4.17.0

- Beside light-v5, not instead of it: both enter the model race that now picks the shown temperature per part of the day ([`docs/scoring.md`](../docs/scoring.md#model-race)); light-v6 is the page's experiment line
- `sky_gate.py`: light-v5's shift times a factor per horizon and sky state. The sky from the VEML7700 alone: illuminance over the brightest reading at the same clock slot in the 14 days before the issue's day; in daylight (sun above 8°) the last hour, otherwise the daylight of the last 24 h; overcast below 0.45, clear above 0.8. Factor: the shift-weighted median of the miss over light-v5's out-of-fold shift, 0 to 1.5; a state without 40 training rows, or no light, keeps light-v5
- Band: light-v5's moved by the scaled shift, widened by its own out-of-fold misses
- Walked forward on the balcony, fitted at local midnight on the days before, temperature 1/2/3/4/5/6 h ahead:
    - 24 September to 10 October 2026: 0.69/0.99/1.24/1.39/1.56/1.62 °C (light-v5 0.69/1.00/1.26/1.45/1.61/1.69, shown 0.80/1.18/1.44/1.60/1.67/1.75, base 0.81/1.27/1.62/1.82/1.88/1.88)
    - 1 to 10 October, targets 7 to 17 h: 1.00/1.45/1.93/1.99/2.22/2.14 °C (light-v5 1.00/1.52/2.05/2.24/2.50/2.54, base 1.09/1.70/2.18/2.34/2.39/2.31)
- Overcast days gain most, mean over 1-6 h for targets 7 to 17 h: 9 October 1.29 °C (light-v5 2.00, base 1.22), 10 October 1.65 °C (2.37, 1.18), 5 October 1.79 °C (2.83, 1.61)
- Clear mornings forecast before sunrise are its weak spot: the night reads yesterday's sky; 6 October 2.49 °C (light-v5 1.74), 7 October 2.51 °C (1.65)
- Tried and dropped: illuminance and humidity straight into light-v5's trees (gained little), a sky state from a classifier trained on ČHMÚ Plzeň-Mikulka sunshine (79 % of windows right leaving each day out, no better as a gate than the illuminance ratio)

## Light experiment light-v5 - 2026-10-07

Model 2026-09-24T08:40:43Z · Server v4.15.0

- Replaces light-v4, whose heating model, fitted on six October mornings, lost to the base model at 1-2 h and 5-6 h
- `sun_correction.py`: per horizon a gradient-boosting model (absolute loss) of the base forecast's miss by day; inputs the temperature swing within each window (sun on the shield, reported since the shield went up), the sun's position at issue and target, the last 1 and 3 h change, the base model's change and its misses verified now; night stays the base
- Fitted once a day by `POST /light-correction` on every day from `FORECAST_HISTORY_SINCE` (17 September 2026), so also on the two weeks before the VEML7700; illuminance not an input (helped some days, hurt others with a week of light)
- Band: base band moved with the median, widened to 80 % by out-of-fold misses (four folds by local day); held 82-85 %
- Issued also from a window without light (light-v4 needed the VEML7700)
- The east facade by its measured normal, 71.8° (sun in front of it from -18.2° to 161.8°), so spring and summer morning sun counts too
- Walked forward on the balcony, fitted at local midnight on the days before, temperature 1/2/3/4/5/6 h ahead:
    - 24 September to 7 October 2026: 0.69/0.96/1.16/1.35/1.49/1.55 °C (shown 0.80/1.17/1.42/1.55/1.60/1.68, base 0.86/1.33/1.70/1.89/1.92/1.89)
    - 30 September to 7 October: 0.63/0.98/1.27/1.51/1.64/1.74 °C (shown 0.69/1.08/1.43/1.67/1.75/1.86, light-v4 0.80/1.21/1.52/1.72/1.92/2.01, base 0.73/1.18/1.55/1.76/1.83/1.89)
- Overcast mornings stay its weak spot: before sunrise it expects the sun most mornings had; 3 to 7 October (fog, low cloud) 4 to 6 h ahead it was level with base: 1.62/1.72/1.86 °C (base 1.60/1.72/1.83, light-v4 1.60/1.78/1.94, shown 1.68/1.79/1.96)
- Tried and dropped: illuminance, pressure tendency, night cooling and the night's humidity rise, yesterday's sun, one model for all horizons, recency weighting (each moved errors between days); quantile models for the band (held 59-77 %)

## Light experiment light-v4 - 2026-10-06

Model 2026-09-24T08:40:43Z · Server v4.14.0

- Replaces light-v3, which scaled solar-time bins by the light and learnt them from four dim mornings, so the VEML hardly moved it
- The shield's heating as a first-order model: a rate per sun azimuth (90-160°) for every 1000 lx above 500 lx, 16.9 % shed per 10 minutes (54 min); fitted offline against the air at ČHMÚ Plzeň-Mikulka and, before 10 h, Plzeň-Slovany, 30 September to 6 October 2026; balcony minus Mikulka with no sun averages 0.0 K
- The base model on the readings with the heating taken out, plus the heating carried to the target with the sky held at its gain now (0.5 in the dark)
- October mornings only: spring and summer sun rising north of 90° heats nothing in the model yet
- Walked forward on the balcony, fitted at local midnight, 2 to 6 October 2026 (the heating rates were fitted on these days); temperature for targets 7 to 12 h, mean over 1-6 h: 1.89 °C (base 1.84, shown 2.64, light-v3 1.89); 6 October, clear: 3.09 °C (base 3.89, light-v3 3.96, shown 1.82); whole day 1.31 °C (base 1.23, light-v3 1.22)
- Tried and dropped: sky held at the 14-day mean (mornings 2.14 °C); a clear-morning guess from the night's temperature, humidity and pressure, trained on 14 ČHMÚ stations 2018-2025 (AUC 0.82 half an hour before sunrise on 2024-2025); on the balcony it read nearly every night as clear and made the mornings 2.18 °C

## Light experiment light-v3 - 2026-10-05

Model 2026-09-24T08:40:43Z · Server v4.13.0

- light-v2 without the recent-error inputs (`error_same`, `error_1h`) from 4 h ahead; 1 to 3 h unchanged. Fitted on sunny mornings, their weights pushed overcast and foggy ones up
- Walked forward on the balcony, fitted at local midnight, 5 October 2026 (fog 8 to 9:40 h), temperature vs light-v2: 4 h 1.74 °C (1.66), 5 h 2.17 °C (2.21), 6 h 2.62 °C (2.73); mornings 7 to 12 h, 4 h 2.36 °C (2.42), 6 h 2.83 °C (2.95); in the fog 4 h 1.60 °C (1.83), 5 h 1.80 °C (2.07). Base lower at every horizon that day
- With 200 history rows instead of 432 also 3 and 4 October: 6 h 1.49 °C (1.67), mornings 6 h 1.65 °C (1.93)
- Tried and dropped: the base model's rise scaled by the missing light and by air near saturation, gain held while saturated. Within 0.05 °C or worse; on 3 October the same damp, dim start (1.4 K above dew point, under 300 lx at 8 h) warmed 6 °C by 10 h, so the station alone does not tell when fog lifts

## Light experiment light-v2 - 2026-10-05

Model 2026-09-24T08:40:43Z · Server v4.11.0

- Fitted on the gain measured at the target instead of at issue; rows without light or a reference do not teach
- Issued with the expected gain: the gain now fading into the target half hour's 14-day mean by 6 h ahead, the mean alone in the dark (light-v1 assumed full sun before dawn, so 8 and 9 h matched shown); no halving from 4 h
- Needs three days of lit history: first fit 5 October 2026
- Walked forward on the balcony, fitted at local midnight, 5 October 2026 (overcast, fog from 9 h), temperature vs shown and light-v1: 3 h 1.18 °C (2.36, 2.18), 6 h 1.72 °C (3.81, 3.26); mornings 7 to 11 h, 3 h 1.69 °C (4.39, 4.01), base 1.60; one day, no clear morning yet

## Light experiment light-v1 - 2026-10-03

Model 2026-09-24T08:40:43Z · Server v4.6.0

- `light_correction.py`, beside correction 3, temperature only; does not change the shown forecast
- Solar inputs scaled by a light gain: smoothed lux over the 90th percentile of the same half hour in the 14 days before (only readings that had arrived by then), capped at 1; solar inputs halved from 4 h ahead
- Walked forward on the balcony, fitted at local midnight, 1 to 3 October 2026, temperature vs shown: 1 h 0.72 °C (0.82), 3 h 1.36 °C (1.47), 6 h 1.48 °C (1.72); without the light gain 1 to 3 h equal shown, so that gain is the lux; part of 4 to 6 h is the halving alone
- 1 October no gain (half a day of light behind its reference); three days only

## Correction 3 - 2026-10-01

Model 2026-09-24T08:40:43Z · Server v4.4.0

- Same regression and bins as correction 2, fitted once a day by `POST /correction` instead of on every forecast; Laravel caches the coefficients and sends them with each forecast
- Forecasts once an hour from the last 56 hours instead of every ten minutes from 60 days
- Up to a day behind the newest verified misses; the `error_same` and `error_1h` inputs are still read at issue time
- Server v4.5.0: forecasts after every upload again, still from 56 hours; version stays 3

## Correction 2 - 2026-09-26

Model 2026-09-24T08:40:43Z · Server v3.10.0

- Daily error shape in solar-time bins (20 minutes from 5 to 12 h, an hour elsewhere) instead of two harmonics
- Fitted on readings from 17 September 2026 (`FORECAST_HISTORY_SINCE`), scored 20 to 26 September: temperature 1 h ahead 0.89 °C (correction 1: 0.99, none: 0.92); 6 to 11 h: 2 h ahead 1.74 °C (2.25), 3 h 2.03 °C (2.45), 6 h 1.92 °C (2.36)
- Still adds warmth on a morning the shield stays in shade
- Server v4.0.5: a sparse history no longer fails the request; a target without a verified row stays uncorrected, `corrected` is true only when every target was corrected; version stays 2

## 2026-09-24T08:40:43Z

Data ČHMÚ 10-minute, 2018-2024, 32 stations below 700 m · Server v3.4.0

- First model: quantile models (10/50/90 %) for temperature, humidity, pressure, 1 to 6 h; classifier for rain within the next n hours
- Inputs: 48 h history of temperature, humidity, pressure; unsettledness of the last 3 h; rain in the last 1 h and 3 h (hidden on 30 % of training rows); solar time and season
- Temperature 1.38 °C (persistence 3.66), humidity 6.4 % (14.4), pressure 0.85 hPa (1.36); 10-90 % range held 76-81 %; rain Brier 0.103 (climatology 0.148), onset AUC 0.79
- Missed the rain of 24 September 2026 at the balcony (1-4 % beforehand)
- Server v4.0.6: 1 h rain chance capped by the 2 h one (alone 50-100 % on dry balcony days, 94 % on the sunny morning of 1 October 2026); correction version stays 2; `base` keeps the classifier's own `rain_probability`
- Server v4.1.0: `POST /base` takes `"full": true` (each horizon as `POST /forecast` without the correction); used nightly for the Plzeň-Mikulka reference
- Server v4.4.0: `"full"` removed with the Plzeň-Mikulka reference

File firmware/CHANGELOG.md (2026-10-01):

# Firmware changelog

One entry per build that went on a board, tagged `fw/v<version>`. `Board` = IDE board selection, `Protocol` = `protocol_version` sent, `Server` = first app release accepting the payload (field map: [`docs/api.md`](../docs/api.md#firmware-and-server-versions)). A build reports itself as `firmware` (and `board` from 2.3) in the `station` object.

- Versions before 2.1.0 had no `FIRMWARE_VERSION`; numbers assigned afterwards from history
- 2.1.1, 2.1.2 and the OTA build of 2.2.0 shipped without a bump; boards on them report the number before
- 2.3.0 never went on a board and has no tag; its changes first shipped with 3.0.0

## 4.0.0 - 2026-09-30

Board ESP32_DEV · Protocol 4 · Server v4.0.0

- Illuminance from the VEML7700: mean, min, max per window in 0.01 lx; omitted when no light data; a failed or saturated read drops only the light
- VEML7700 steps through five ranges, 0.03 lx per count at dusk to 141 klx in full sun, one step per reading
- Parked noise task polls its flag every 100 ms (a resume racing the park left the microphone off until the next upload)
- Flash buffer format version 3; windows buffered by older builds are discarded on first boot

## 3.0.3 - 2026-09-30

Board ESP32_DEV · Protocol 3 · Server v3.0.1

- Microphone SCK and WS stop for every sensor read (coupling into SDA/SCL over 4 m made the VEML7700 miss about every other transfer); costs about 0.5 s of noise per reading
- SCK and WS on the weakest GPIO driver

## 3.0.2 - 2026-09-23

Board ESP32_DEV · Protocol 3 · Server v3.0.1

- A microphone that fails to start gives its ~40 kB buffers back at once (before, every upload ran short of heap)
- A resume that found no memory is retried every minute from the loop

## 3.0.1 - 2026-09-23

Board ESP32_DEV · Protocol 3 · Server v3.0.1

- I2C at 20 kHz instead of 100 kHz, for the 4 m cable to the SHT41
- Noise task gives its ~40 kB back for every upload (held, mbedTLS could not allocate, largest free block 36 kB, upload hung until the watchdog); a window's noise misses the seconds of its upload
- Transport errors log mbedTLS's reason and the largest free block

## 3.0.0 - 2026-09-23

Board ESP32_DEV · Protocol 3 · Server v3.0.1

- New board: ESP32-WROOM-32 (`esp32:esp32:esp32`, _ESP32 Dev Module_), still `min_spiffs`; C3's shared-LED workaround removed; first build with 2.3.0's `board` field
- New sensors: SHT41 in the radiation shield outside (`temperature`, `humidity`), BMP280 on the base board indoors (`pressure`); BME280 retired (before 3.0 all three came from it)
- Noise from an INMP441 over I2S: per window `laeq`, `lamax`, `la10`, `la90` in 0.01 dB(A) and 26 third-octave bands 25 Hz - 8 kHz, as a `noise` object (protocol 3); FFT task on core 0, loop on core 1
- Window buffer file version 2 (older buffer dropped at boot); payload buffer 16 kB

## 2.3.0 - unreleased

Board ESP32C3_DEV · Protocol 2 · Server v3.0.0

- `board` (`ARDUINO_BOARD`) in the station report and on the LAN status page
- Builds for `esp32:esp32:esp32` (ESP32-WROOM-32) as well

## 2.2.0 - 2026-09-18

Board ESP32C3_DEV · Protocol 2 · Server v2.2.0

- Clock drift per SNTP re-sync reported as `clock_step_ms`, `clock_step_over_s`, `clock_step_max_ms`, `clock_synced_at` (optional on the server as a set)
- OTA with `ArduinoOTA`: password from `secrets.h`, port advertised over mDNS
- Partition scheme `min_spiffs` for the second app slot (wiped the filesystem once)

## 2.1.2 - 2026-09-17

Board ESP32C3_DEV · Protocol 2 · Server v2.1.0 · reports itself as 2.1.0

- Logs the driver's disconnect reason once per outage
- Fails over to the backup network after a minute without association, not only after failed uploads

## 2.1.1 - 2026-09-17

Board ESP32C3_DEV · Protocol 2 · Server v2.1.0 · reports itself as 2.1.0

- HTTP server started after `wifiBegin()` (2.1.0 boot-looped on an lwIP assert)

## 2.1.0 - 2026-09-17

Board ESP32C3_DEV · Protocol 2 · Server v2.1.0

- `FIRMWARE_VERSION` and a `station` object with every batch (firmware, reset reason, uptime, heap, network, RSSI, buffered windows, failed uploads); servers before v2.1.0 ignore it
- Window buffer mirrored to LittleFS; a restart loses only the window being filled
- LAN status page (`/`, `/status`, `/log`, `/log/flash`) and mDNS
- Backup WiFi network, switched on failed uploads
- Task watchdog; restart after an hour with a backlog and no 2xx

## 2.0.0 - 2026-09-16

Board ESP32C3_DEV (ESP32-C3-DevKitM-1) · Protocol 2 · Server v2.0.0

- Mains powered over USB, no deep sleep; a reading every half minute, aggregated into ten-minute epoch windows with mean, extremes and sample count (**protocol 2**; a V1 server refuses the batch)
- RTC storage dropped; I2C on GPIO8/GPIO9 via `SDA`/`SCL` macros; on-board RGB LED shares GPIO8 and is blanked after every transfer (`RGB_LED_ON_SDA`)

## 1.6.0 - 2026-09-09

Board DFROBOT_FIREBEETLE_2_ESP32C6 · Protocol 1 · Server v1.0.0

- Full TX power, no modem sleep on the uplink

## 1.5.0 - 2026-09-09

Board DFROBOT_FIREBEETLE_2_ESP32C6 (DFRobot FireBeetle 2 ESP32-C6, DFR1075) · Protocol 1 · Server v1.0.0

- Board change from ESP32-WROOM-32: RISC-V, ESP32 core 3.x, native USB serial, LED on GPIO15; payload unchanged

## 1.4.0 - 2026-09-07

Board ESP32_DEV · Protocol 1 · Server v1.0.0

- LED blinks at power-up and on the first delivered upload only

## 1.3.0 - 2026-09-05

Board ESP32_DEV · Protocol 1 · Server v1.0.0

- Logs RSSI and the reason when an upload fails

## 1.2.0 - 2026-09-05

Board ESP32_DEV · Protocol 1 · Server v1.0.0

- LED signals a delivered upload only

## 1.1.0 - 2026-09-05

Board ESP32_DEV · Protocol 1 · Server v1.0.0

- Each wakeup reported on the on-board LED

## 1.0.2 - 2026-09-05

Board ESP32_DEV · Protocol 1 · Server v1.0.0

- Clock re-synced hourly

## 1.0.1 - 2026-09-05

Board ESP32_DEV · Protocol 1 · Server v1.0.0

- Clock synced against the server after drifting minutes ahead

## 1.0.0 - 2026-09-04

Board ESP32_DEV (ESP32-WROOM-32) · Protocol 1 · Server v1.0.0

- First sketch: deep sleep between ten-minute wakeups, one reading per wakeup, unsent readings in RTC memory (**protocol 1**: `timestamp`, `temperature`, `humidity`, `pressure`)

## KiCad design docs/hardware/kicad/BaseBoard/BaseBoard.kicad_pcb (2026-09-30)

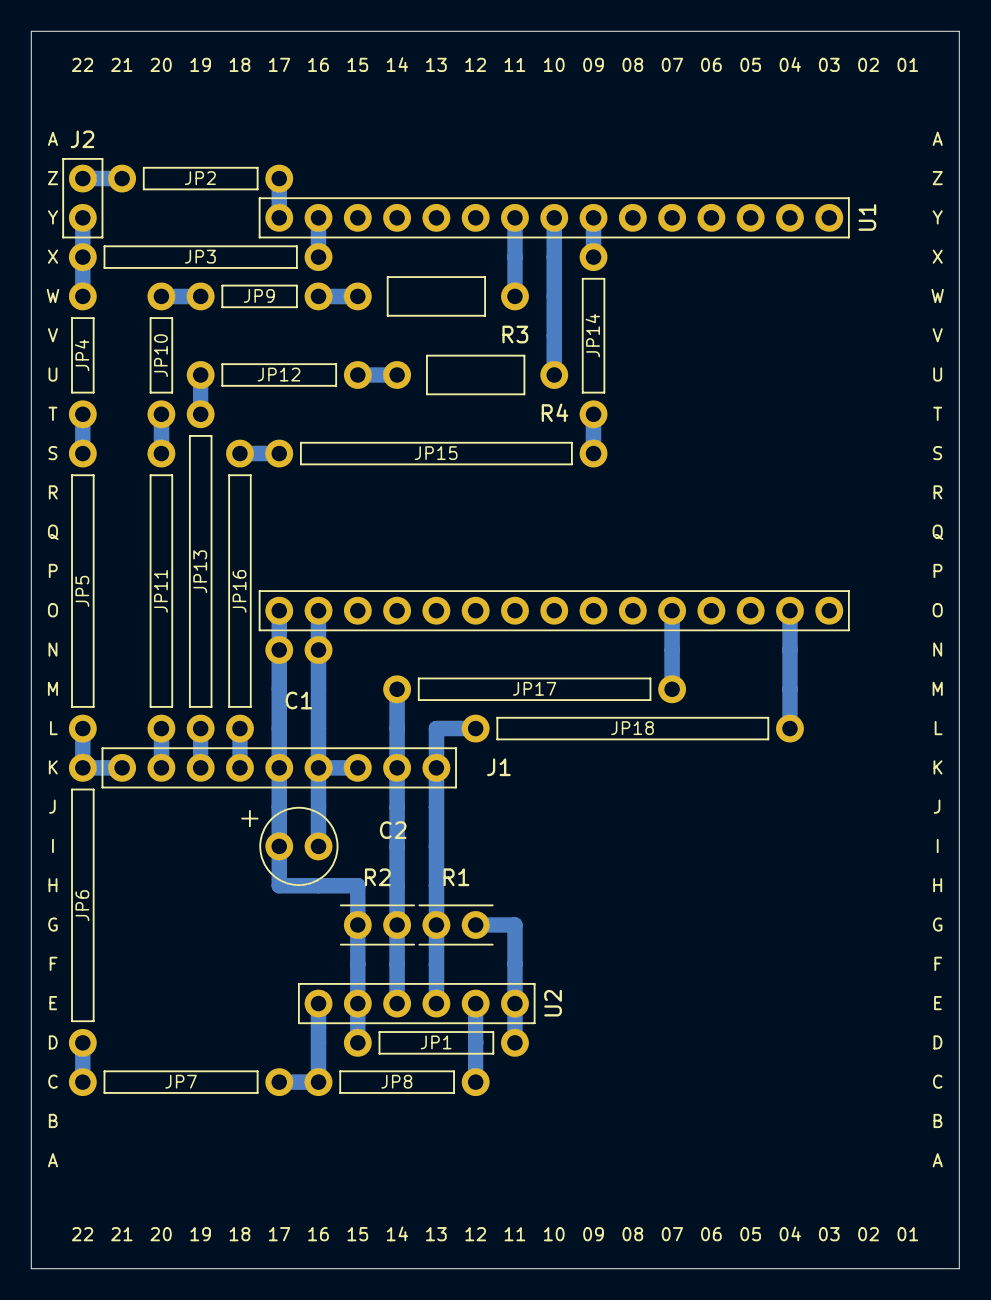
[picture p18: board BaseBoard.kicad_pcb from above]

Board: 2 copper layers, 60.0 x 80.0 mm, 29 parts (0 on the bottom side), 10 nets.

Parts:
C1: 100n; C_Disc_P2.54
C2: 10u; CP_Radial_D5.0mm_P2.54
J1: FTP cable; PinHeader_1x09
J2: 5V in; PinHeader_1x02
JP1, JP2, JP8, JP12, JP14: 0R; R_Jumper_P10.16
JP3: 0R; R_Jumper_P15.24
JP4, JP9, JP10: 0R; R_Jumper_P7.62
JP5, JP6, JP11, JP16, JP17: 0R; R_Jumper_P17.78
JP7: 0R; R_Jumper_P12.70
JP13, JP15, JP18: 0R; R_Jumper_P20.32
PERF1: perfboard 22 x 27; Perfboard_22x27
R1, R2: 4k7; R_Socketed_1x02
R3, R4: 47R; R_Axial_P10.16
U1: ESP32 DevKit V1; DOIT_ESP32_DevKit_V1_Socketed
U2: BMP280 0x76; BMP280_Module_Socketed

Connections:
+3V3: C1.1, C2.1, J1.5, JP1.1, JP1.2, R1.1, R2.1, U1.16, U2.1, U2.5
+5V: J2.1, JP2.1, JP2.2, U1.1
/SCK: R3.1, U1.7
/SCK_CABLE: J1.2, JP9.1, JP9.2, JP10.1, JP10.2, JP11.1, JP11.2, R3.2
/SCL: J1.9, JP18.1, JP18.2, R1.2, U1.29, U2.3
/SD: J1.4, JP14.1, JP14.2, JP15.1, JP15.2, JP16.1, JP16.2, U1.9
/SDA: J1.8, JP17.1, JP17.2, R2.2, U1.26, U2.4
/WS: R4.1, U1.8
/WS_CABLE: J1.3, JP12.1, JP12.2, JP13.1, JP13.2, R4.2
GND: C1.2, C2.2, J1.1, J1.6, J1.7, J2.2, JP3.1, JP3.2, JP4.1, JP4.2, JP5.1, JP5.2, JP6.1, JP6.2, JP7.1, JP7.2, JP8.1, JP8.2, U1.2, U1.17, U2.2, U2.6

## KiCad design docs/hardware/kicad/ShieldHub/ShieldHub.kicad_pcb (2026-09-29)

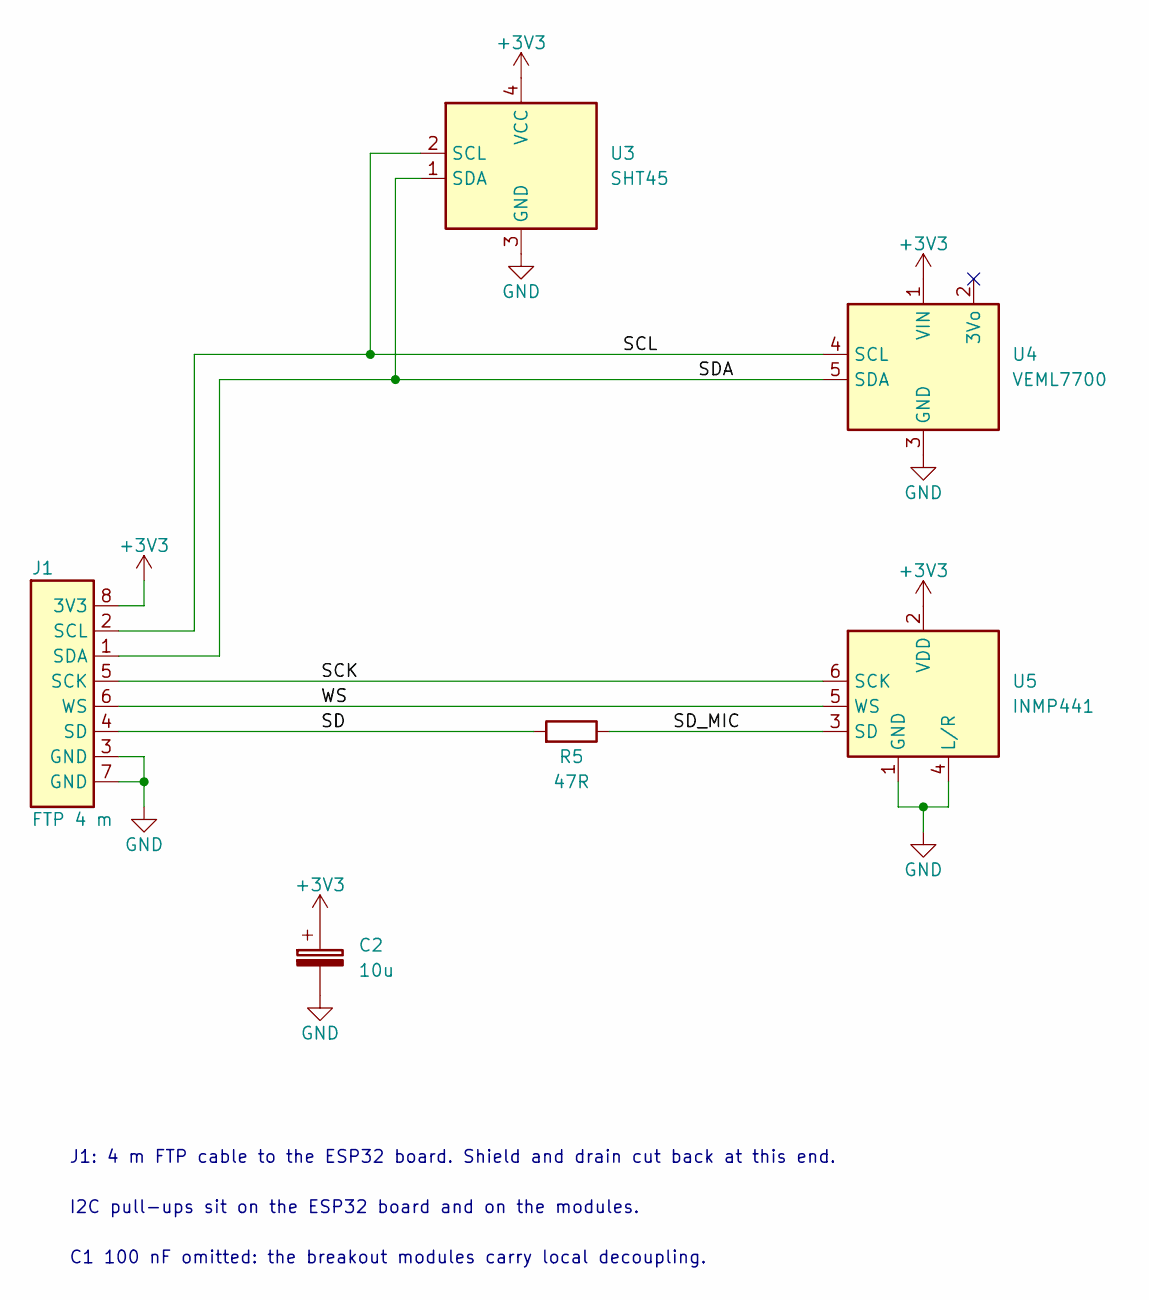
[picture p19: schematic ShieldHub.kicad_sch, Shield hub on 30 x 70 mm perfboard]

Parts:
C2: 10u; C_Radial_P2_54
J1: FTP 4 m; FTP_8_Wires
R5: 47R; R_Axial_P9_16
U3: SHT45; SHT45_LaskaKit
U4: VEML7700; VEML7700_Techfun
U5: INMP441; INMP441_Round

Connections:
+3V3: C2.1 (+), J1.8 (3V3), U3.4 (VCC), U4.1 (VIN), U5.2 (VDD)
/SCK: J1.5 (SCK), U5.6 (SCK)
/SCL: J1.2 (SCL), U3.2 (SCL), U4.4 (SCL)
/SD: J1.4 (SD), R5.1
/SDA: J1.1 (SDA), U3.1 (SDA), U4.5 (SDA)
/SD_MIC: R5.2, U5.3 (SD)
/WS: J1.6 (WS), U5.5 (WS)
GND: C2.2 (-), J1.3 (GND), J1.7 (GND), U3.3 (GND), U4.3 (GND), U5.1 (GND), U5.4 (L/R)

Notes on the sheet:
J1: 4 m FTP cable to the ESP32 board. Shield and drain cut back at this end.
I2C pull-ups sit on the ESP32 board and on the modules.
C1 100 nF omitted: the breakout modules carry local decoupling.

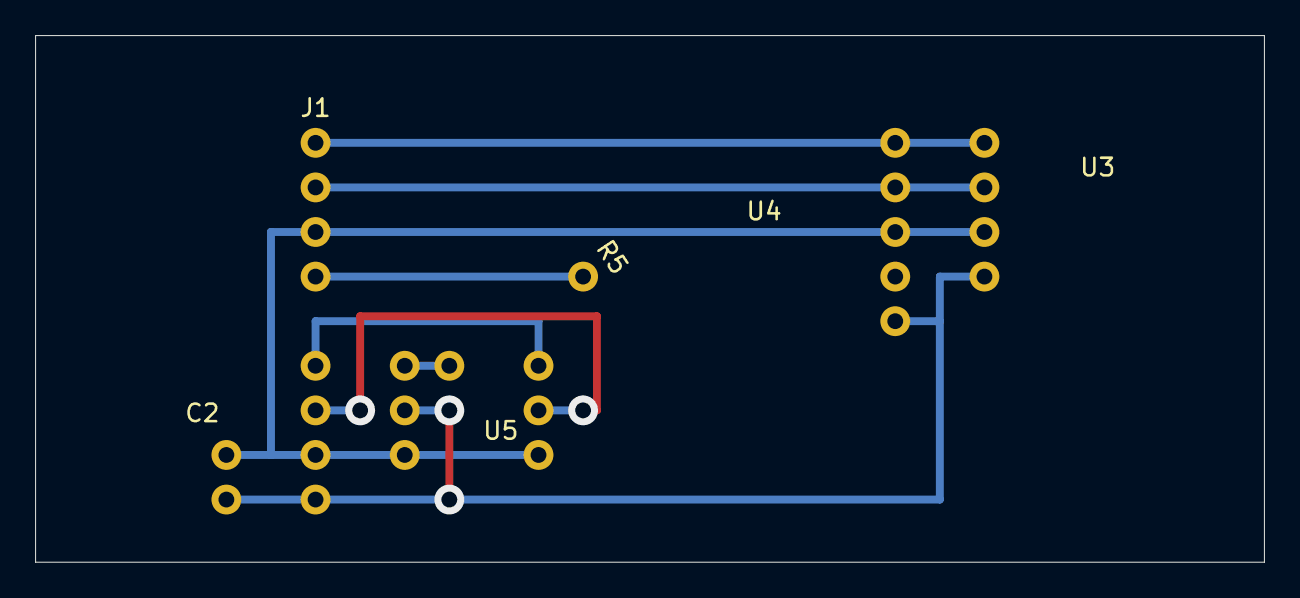
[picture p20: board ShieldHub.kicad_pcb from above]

Board: 2 copper layers, 70.0 x 30.0 mm, 6 parts (0 on the bottom side), 8 nets.

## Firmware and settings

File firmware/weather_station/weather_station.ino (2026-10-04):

#include <stdint.h>
#include <time.h>

#include <WiFi.h>
#include <WiFiClientSecure.h>
#include <HTTPClient.h>
#include <ArduinoOTA.h>
#include <esp_sntp.h>
#include <esp_system.h>
#include <esp_timer.h>
#include <esp_task_wdt.h>

#include <Wire.h>
#include <Adafruit_BMP280.h>
#include <Adafruit_SHT4x.h>

#include <secrets.h>

#include "ca_certs.h"
#include "noise.h"
#include "station_http.h"
#include "station_log.h"
#include "station_status.h"
#include "transmission_json.h"
#include "veml7700.h"
#include "window.h"
#include "window_buffer.h"

// Bump per flashed build; tag fw/v<version>.
#define FIRMWARE_VERSION "4.0.0"

// Board id from the IDE (build.board), sent with every batch.
#ifndef ARDUINO_BOARD
#define ARDUINO_BOARD "unknown"
#endif
#define FIRMWARE_BOARD ARDUINO_BOARD

// WROOM-32 hardware I2C (GPIO21/22); BMP280 on the base board, SHT4x at the end of the 4 m cable, same bus.
#define I2C_SDA_PIN SDA
#define I2C_SCL_PIN SCL

// 20 kHz instead of 100: the 4 m cable's capacitance and radio coupling.
#define I2C_CLOCK_HZ 20000

#define API_URL "https://weather.rajtik.com/api/v1/measurement"

// 20 readings per ten-minute window; slow enough that self-heating stays negligible.
static const uint32_t SAMPLE_INTERVAL_MS = 30000;

static const uint32_t NOISE_TAKE_WAIT_MS = 500;

static const uint32_t WIFI_TIMEOUT_MS = 15000;
static const uint32_t NTP_TIMEOUT_MS = 10000;

// Reconnect nudge; failover after this long down; retry of the primary while on the backup.
static const uint32_t WIFI_RETRY_MS = 30000;
static const uint32_t WIFI_FAILOVER_MS = 60000;
static const uint32_t WIFI_PRIMARY_RETRY_MS = 3600000;

// This many failures in a row while associated: uplink behind the AP is down, switch network.
static const uint32_t UPLOAD_RETRY_MS = 60000;
static const uint16_t UPLOAD_FAILURES_BEFORE_SWITCH = 3;

// Backlog and no successful upload for this long: restart (the buffer is on flash).
static const uint32_t NO_UPLOAD_RESTART_MS = 3600000;

// Long enough for a full backlog to go out.
static const uint32_t WATCHDOG_TIMEOUT_MS = 120000;

// Display only; stamps are UTC.
static const char* TZ_PRAGUE = "CET-1CEST,M3.5.0,M10.5.0/3";

// The crystal drifts seconds a day and the server stores stamps verbatim.
static const uint32_t NTP_RESYNC_AFTER_S = 3600UL;

// ---------------------------------------------------------------- status

static station_status_t status;

static const char* resetReasonName(esp_reset_reason_t reason) {
  switch (reason) {
    case ESP_RST_POWERON: return "power on";
    case ESP_RST_EXT: return "external reset";
    case ESP_RST_SW: return "software restart";
    case ESP_RST_PANIC: return "panic";
    case ESP_RST_INT_WDT: return "interrupt watchdog";
    case ESP_RST_TASK_WDT: return "task watchdog";
    case ESP_RST_WDT: return "other watchdog";
    case ESP_RST_DEEPSLEEP: return "deep sleep";
    case ESP_RST_BROWNOUT: return "brownout";
    case ESP_RST_SDIO: return "sdio";
    default: return "unknown";
  }
}

static void refreshStatus() {
  status.firmware = FIRMWARE_VERSION;
  status.board = FIRMWARE_BOARD;
  status.uptime_s = (uint32_t)(esp_timer_get_time() / 1000000LL);
  status.heap_free = ESP.getFreeHeap();
  status.heap_min = ESP.getMinFreeHeap();
  status.clock_set = stationClockIsSet();
  status.online = WiFi.status() == WL_CONNECTED;
  status.buffered = windowBufferCount();

  if (status.online) {
    strncpy(status.ssid, WiFi.SSID().c_str(), sizeof(status.ssid) - 1);
    status.ssid[sizeof(status.ssid) - 1] = '\0';
    strncpy(status.ip, WiFi.localIP().toString().c_str(), sizeof(status.ip) - 1);
    status.ip[sizeof(status.ip) - 1] = '\0';
    status.rssi = (int8_t)WiFi.RSSI();
  } else {
    status.rssi = 0;
  }
}

// ---------------------------------------------------------------- sensors

static Adafruit_BMP280 bmp(&Wire);
static Adafruit_SHT4x sht;

// Pressure only: it sits indoors, so its temperature is never sent.
static bool bmp280Begin() {
  // Address depends on the SDO strap.
  if (!bmp.begin(0x76) && !bmp.begin(0x77)) {
    logInfo("BMP280 not found");
    return false;
  }

  bmp.setSampling(Adafruit_BMP280::MODE_FORCED,
                  Adafruit_BMP280::SAMPLING_X1,  // temperature, needed for the pressure compensation
                  Adafruit_BMP280::SAMPLING_X1,
                  Adafruit_BMP280::FILTER_OFF);
  return true;
}

static bool sht4xBegin() {
  if (!sht.begin(&Wire)) {
    logInfo("SHT4x not found");
    return false;
  }

  sht.setPrecision(SHT4X_HIGH_PRECISION);
  sht.setHeater(SHT4X_NO_HEATER);

  // The first read after begin() often fails; spend it here.
  sensors_event_t humidity, temp;
  sht.getEvent(&humidity, &temp);
  return true;
}

static bool sensorsBegin() {
  Wire.begin(I2C_SDA_PIN, I2C_SCL_PIN);
  Wire.setClock(I2C_CLOCK_HZ);
  bool bmpFound = bmp280Begin();
  bool shtFound = sht4xBegin();

  // Not waited for; vemlRead() keeps trying.
  vemlBegin();
  return bmpFound && shtFound;
}

static bool readSensors(station_reading_t& out) {
  // All I2C traffic happens with the mic clocks stopped.
  sensors_event_t humidityEvent, tempEvent;
  float p = NAN;
  uint32_t illuminance = 0;
  noiseHush();
  const bool shtRead = sht.getEvent(&humidityEvent, &tempEvent);
  const bool bmpRead = shtRead && bmp.takeForcedMeasurement();
  if (bmpRead) {
    p = bmp.readPressure();                      // Pa, the unit the API takes
  }
  const bool lightRead = vemlRead(illuminance);
  noiseUnhush();

  if (!shtRead) {
    logInfo("SHT4x measurement failed");
    return false;
  }

  if (!bmpRead) {
    logInfo("BMP280 measurement failed");
    return false;
  }

  float t = tempEvent.temperature;               // degC
  float h = humidityEvent.relative_humidity;     // %

  if (isnan(t) || isnan(h) || isnan(p)) {
    logInfo("sensors returned NaN: t=%.2f h=%.2f p=%.0f", t, h, p);
    return false;
  }

  long temperature = lroundf(t * 100.0f);
  long humidity = lroundf(h * 100.0f);
  long pressure = lroundf(p);

  // Out of range would get the whole batch rejected and block the queue.
  if (temperature < READING_TEMP_MIN || temperature > READING_TEMP_MAX ||
      humidity < READING_HUMIDITY_MIN || humidity > READING_HUMIDITY_MAX ||
      pressure < READING_PRESSURE_MIN || pressure > READING_PRESSURE_MAX) {
    logInfo("reading out of range: t=%ld h=%ld p=%ld", temperature, humidity, pressure);
    return false;
  }

  out.timestamp = (uint32_t)time(nullptr);  // UTC
  out.temperature = (int16_t)temperature;
  out.humidity = (uint16_t)humidity;
  out.pressure = (uint32_t)pressure;

  // Out-of-range light is dropped; the rest of the reading stays.
  out.has_illuminance = lightRead && illuminance <= READING_ILLUMINANCE_MAX;
  out.illuminance = out.has_illuminance ? illuminance : 0;

  if (out.has_illuminance) {
    logTrace("SHT4x: %.2f C  %.2f %%  BMP280: %.2f hPa  VEML7700: %.2f lx", t, h, p / 100.0f, illuminance / 100.0f);
  } else {
    logTrace("SHT4x: %.2f C  %.2f %%  BMP280: %.2f hPa  VEML7700: none", t, h, p / 100.0f);
  }
  return true;
}

// ---------------------------------------------------------------- network

typedef struct {
  const char* ssid;
  const char* pass;
} wifi_network_t;

static const wifi_network_t WIFI_NETWORKS[] = {
  { PRIMARY_WIFI_SSID, PRIMARY_WIFI_PASS },
  { BACKUP_WIFI_SSID, BACKUP_WIFI_PASS },
};

static uint8_t wifiNetworkCount() {
  return BACKUP_WIFI_SSID[0] == '\0' ? 1 : 2;
}

static bool otaListening = false;

static uint8_t wifiCurrent = 0;
static uint32_t wifiSwitchedMs = 0;
static uint32_t wifiKickedMs = 0;
static uint32_t wifiDownSinceMs = 0;  // when the current outage began; 0 while online
static bool wifiEverBegan = false;

// Disconnect reason is the only place a wrong password or missing AP shows up.
// The handler runs on the event task: it only notes, the loop logs (reportWifiEvents()).
static volatile bool wifiEventGotIp = false;
static volatile bool wifiEventLostIp = false;
static volatile bool wifiEventDisconnected = false;
static volatile uint8_t wifiEventReason = 0;

static void onWifiEvent(WiFiEvent_t event, WiFiEventInfo_t info) {
  switch (event) {
    case ARDUINO_EVENT_WIFI_STA_DISCONNECTED:
      wifiEventReason = info.wifi_sta_disconnected.reason;
      wifiEventDisconnected = true;
      break;
    case ARDUINO_EVENT_WIFI_STA_GOT_IP:
      wifiEventGotIp = true;
      break;
    case ARDUINO_EVENT_WIFI_STA_LOST_IP:
      wifiEventLostIp = true;
      break;
    default:
      break;
  }
}

// Once per reason: the core retries every few seconds and would flush the flash log.
static void reportWifiEvents() {
  static uint8_t lastReason = 0;

  if (wifiEventGotIp) {
    wifiEventGotIp = false;
    lastReason = 0;
    logInfo("WiFi: got IP %s", WiFi.localIP().toString().c_str());
  }

  if (wifiEventLostIp) {
    wifiEventLostIp = false;
    logInfo("WiFi: lost IP");
  }

  if (wifiEventDisconnected) {
    wifiEventDisconnected = false;
    uint8_t reason = wifiEventReason;

    bool selfInflicted = reason == WIFI_REASON_ASSOC_LEAVE || reason == WIFI_REASON_STA_LEAVING;
    if (!selfInflicted && reason != lastReason) {
      lastReason = reason;
      logInfo("WiFi: disconnected, reason %u (%s)", reason,
              WiFi.STA.disconnectReasonName((wifi_err_reason_t)reason));
    }
  }
}

static bool waitForWifi(uint32_t timeoutMs) {
  uint32_t start = millis();
  while (millis() - start < timeoutMs) {
    if (WiFi.status() == WL_CONNECTED) return true;
    delay(100);
  }
  return false;
}

// -70 dBm is fine, -80 marginal, past -85 it associates but a TLS upload does not survive.
static void reportVisibleAps() {
  // A scan fails while associating.
  WiFi.disconnect();
  delay(200);

  int found = WiFi.scanNetworks();

  if (found < 0) {
    logInfo("scan: failed (%d)", found);
  } else if (found == 0) {
    logInfo("scan: nothing on the air");
  }

  for (int i = 0; i < found; i++) {
    const char* ours = "";
    for (uint8_t n = 0; n < wifiNetworkCount(); n++) {
      if (WiFi.SSID(i) == WIFI_NETWORKS[n].ssid) ours = "  <- ours";
    }

    logInfo("scan: %s  %ld dBm  ch %ld%s", WiFi.SSID(i).c_str(), (long)WiFi.RSSI(i), (long)WiFi.channel(i), ours);
  }

  WiFi.scanDelete();

  // Resume the interrupted network; restart the kick timer so the nudge does not hit the forming association.
  wifiKickedMs = millis();
  WiFi.begin(WIFI_NETWORKS[wifiCurrent].ssid, WIFI_NETWORKS[wifiCurrent].pass);
}

static void wifiConnectTo(uint8_t network) {
  wifiCurrent = network;
  wifiSwitchedMs = millis();
  wifiKickedMs = millis();
  wifiDownSinceMs = millis();
  status.wifi_network = network;

  logInfo("WiFi: joining %s (%s)", WIFI_NETWORKS[network].ssid, network == 0 ? "primary" : "backup");

  // Not on the first join: a stray event while the association forms.
  if (wifiEverBegan) {
    WiFi.disconnect();
  }
  wifiEverBegan = true;

  WiFi.begin(WIFI_NETWORKS[network].ssid, WIFI_NETWORKS[network].pass);
}

static void wifiSwitch(const char* why) {
  if (wifiNetworkCount() < 2) {
    return;
  }

  status.wifi_switches++;
  logInfo("WiFi: %s, switching network", why);
  wifiConnectTo(wifiCurrent == 0 ? 1 : 0);
}

static void wifiBegin() {
  WiFi.onEvent(onWifiEvent);
  WiFi.setHostname(STATION_HOSTNAME);
  WiFi.mode(WIFI_STA);
  WiFi.persistent(false);
  WiFi.setAutoReconnect(true);
  wifiConnectTo(0);
}

// Returns whether online. Only the first association is waited for; later drops are nudged, then failed over.
static bool ensureWifi() {
  static bool wasConnected = false;

  if (WiFi.status() == WL_CONNECTED) {
    if (!wasConnected) {
      logInfo("WiFi connected to %s, %s, RSSI %d dBm",
              WiFi.SSID().c_str(), WiFi.localIP().toString().c_str(), WiFi.RSSI());
      wasConnected = true;
      wifiDownSinceMs = 0;
      stationHttpAnnounce(otaListening);
    }

    // Only with an empty buffer so the try costs no data.
    if (wifiCurrent != 0 && windowBufferCount() == 0 && millis() - wifiSwitchedMs >= WIFI_PRIMARY_RETRY_MS) {
      logInfo("WiFi: trying the primary again");
      wifiConnectTo(0);
      return false;
    }

    return true;
  }

  if (wasConnected) {
    logInfo("WiFi lost");
    wasConnected = false;
    wifiDownSinceMs = millis();
  }

  if (millis() - wifiDownSinceMs >= WIFI_FAILOVER_MS && wifiNetworkCount() > 1) {
    wifiSwitch("down too long");
    return false;
  }

  if (millis() - wifiKickedMs < WIFI_RETRY_MS) {
    return false;
  }

  wifiKickedMs = millis();
  WiFi.disconnect();
  WiFi.begin(WIFI_NETWORKS[wifiCurrent].ssid, WIFI_NETWORKS[wifiCurrent].pass);

  return false;
}

// ---------------------------------------------------------------- clock

static volatile bool ntpAnswered = false;

static volatile bool clockStepPending = false;
static volatile int32_t clockStepMs = 0;
static volatile uint32_t clockStepOverS = 0;

// Replaces the stock sntp_sync_time() to read the clock before stepping it; the step is the drift.
// The first answer after boot is skipped (steps from 1970, or an RTC clock of unknown age).
// Runs on lwIP's task: no logging here.
extern "C" void sntp_sync_time(struct timeval* tv) {
  struct timeval before;
  gettimeofday(&before, nullptr);
  settimeofday(tv, nullptr);

  uint32_t previousSyncAt = status.clock_synced_at;
  status.clock_synced_at = (uint32_t)tv->tv_sec;

  if (previousSyncAt != 0) {
    int64_t stepUs = (int64_t)(tv->tv_sec - before.tv_sec) * 1000000LL + (tv->tv_usec - before.tv_usec);
    int32_t stepMs = (int32_t)(stepUs / 1000);

    status.clock_step_ms = stepMs;
    status.clock_step_over_s = (uint32_t)tv->tv_sec - previousSyncAt;
    if (labs(stepMs) > labs(status.clock_step_max_ms)) {
      status.clock_step_max_ms = stepMs;
    }

    clockStepMs = stepMs;
    clockStepOverS = status.clock_step_over_s;
    clockStepPending = true;
  }

  ntpAnswered = true;
}

static void reportClockStep() {
  if (!clockStepPending) {
    return;
  }

  clockStepPending = false;
  logInfo("clock stepped %+ld ms after %lu s", (long)clockStepMs, (unsigned long)clockStepOverS);
}

// Whenever online, never gated on the clock: it survives a software restart in the RTC.
static void sntpBegin() {
  static bool started = false;

  if (started) {
    return;
  }

  esp_sntp_set_sync_interval(NTP_RESYNC_AFTER_S * 1000UL);
  sntp_set_sync_mode(SNTP_SYNC_MODE_IMMED);
  configTzTime(TZ_PRAGUE, "pool.ntp.org", "time.nist.gov");
  started = true;
}

// Waits on the SNTP answer, not on the clock looking plausible.
static bool syncClock(uint32_t timeoutMs) {
  sntpBegin();

  uint32_t start = millis();
  while (millis() - start < timeoutMs) {
    if (ntpAnswered && stationClockIsSet()) {
      logInfo("clock synced");
      return true;
    }
    delay(200);
  }

  logInfo("NTP timed out");
  return false;
}

// ---------------------------------------------------------------- upload

// Unconfigured: windows stay buffered and no failure handling applies.
static bool uploadConfigured() {
  return API_URL[0] != '\0' && BEARER_TOKEN[0] != '\0';
}

static bool postTransmission(const char* payload) {
  WiFiClientSecure client;
  client.setCACert(ROOT_CA_BUNDLE);

  HTTPClient http;
  http.begin(client, API_URL);
  http.addHeader("Content-Type", "application/json");
  http.addHeader("Authorization", "Bearer " BEARER_TOKEN);

  int code = http.POST((uint8_t*)payload, strlen(payload));

  status.last_post_code = code;
  status.last_post_at = (uint32_t)time(nullptr);

  // Negative: client side failure, most often the TLS handshake.
  if (code < 0) {
    // The largest free block says whether the TLS buffers fitted.
    char tlsError[96];
    int tlsCode = client.lastError(tlsError, sizeof(tlsError));
    logInfo("POST -> %d, transport error: %s; TLS %d: %s; largest free block %u",
            code, http.errorToString(code).c_str(), tlsCode, tlsError, (unsigned)ESP.getMaxAllocHeap());
  } else if (code == 401 || code == 422) {
    // 422: payload does not match the contract; the body names the field.
    logInfo("POST -> %d: %s", code, http.getString().c_str());
  } else {
    logInfo("POST -> %d", code);
  }

  http.end();
  return code >= 200 && code < 300;
}

static uint32_t lastUploadAttemptMs = 0;
static uint32_t lastUploadOkMs = 0;

static void uploadBatches(char* payload, size_t payloadLen);

// Oldest first, stops at the first failure. The server upserts: resending is safe.
static void uploadBuffered() {
  static char payload[TRANSMISSION_PAYLOAD_BYTES];

  lastUploadAttemptMs = millis();

  if (!uploadConfigured()) {
    logInfo("no API URL or token set, keeping %u windows buffered", windowBufferCount());
    return;
  }

  // TLS needs the noise task's buffers.
  noisePause();
  uploadBatches(payload, sizeof(payload));
  noiseResume();
}

static void uploadBatches(char* payload, size_t payloadLen) {
  while (windowBufferCount() > 0) {
    transmission_t tx;
    windowBufferToTransmission(tx, DEVICE_ID);
    refreshStatus();

    if (!transmissionToJson(tx, status, payload, payloadLen)) {
      logInfo("payload buffer too small");
      return;
    }

    if (!postTransmission(payload)) {
      status.upload_failures++;
      logInfo("keeping %u windows buffered, %u failures in a row", windowBufferCount(), status.upload_failures);

      if (status.upload_failures >= UPLOAD_FAILURES_BEFORE_SWITCH && wifiNetworkCount() > 1) {
        status.upload_failures = 0;
        wifiSwitch("uploads keep failing");
      }
      return;
    }

    status.upload_failures = 0;
    status.last_upload_ok_at = (uint32_t)time(nullptr);
    lastUploadOkMs = millis();
    windowBufferDrop(tx.data_count);
    esp_task_wdt_reset();
  }
}

// ---------------------------------------------------------------- cycle

static window_t window;
static bool windowOpen = false;
static uint32_t lastSampleMs = 0;

static void closeWindow() {
  station_window_t entry;

  if (!windowClose(window, entry)) {
    return;
  }

  // The noise task closes a slot on its first frame past the boundary.
  if (noiseTake(window.slot, entry.noise, NOISE_TAKE_WAIT_MS)) {
    logInfo("noise %lu: LAeq %d  LAmax %d  LA10 %d  LA90 %d  (0.01 dB)  s=%u",
            (unsigned long)window.slot, entry.noise.laeq, entry.noise.lamax,
            entry.noise.la10, entry.noise.la90, entry.noise.seconds);
  } else {
    noise_stats_t n = noiseStats();
    logInfo("noise %lu: none (running %d, frames %lu, silent %lu, short reads %lu)",
            (unsigned long)window.slot, n.running, (unsigned long)n.frames,
            (unsigned long)n.silent_frames, (unsigned long)n.short_reads);
  }

  logInfo("window %lu: t=%d [%d..%d]  h=%u [%u..%u]  p=%lu [%lu..%lu]  l=%lu [%lu..%lu]/%u  n=%u",
          (unsigned long)entry.timestamp,
          entry.temperature, entry.temperature_min, entry.temperature_max,
          entry.humidity, entry.humidity_min, entry.humidity_max,
          (unsigned long)entry.pressure, (unsigned long)entry.pressure_min,
          (unsigned long)entry.pressure_max,
          (unsigned long)entry.illuminance, (unsigned long)entry.illuminance_min,
          (unsigned long)entry.illuminance_max, entry.illuminance_samples,
          entry.samples);

  if (!windowBufferAdd(entry)) {
    logInfo("buffer full, oldest window dropped");
  }
}

static void restartIfStuck() {
  if (!uploadConfigured() || windowBufferCount() == 0 || millis() - lastUploadOkMs < NO_UPLOAD_RESTART_MS) {
    return;
  }

  logInfo("no upload for an hour with %u windows waiting, restarting", windowBufferCount());
  delay(200);
  ESP.restart();
}

// ---------------------------------------------------------------- ota

// OTA blocks the loop: the progress callback feeds the watchdog, a stalled transfer still trips it.
// Off without a password.
static void otaBegin() {
  if (OTA_PASSWORD[0] == '\0') {
    logInfo("no OTA password set, OTA off");
    return;
  }

  ArduinoOTA.setHostname(STATION_HOSTNAME);
  ArduinoOTA.setPort(STATION_OTA_PORT);
  ArduinoOTA.setPassword(OTA_PASSWORD);
  // The HTTP module owns mDNS and advertises OTA too.
  ArduinoOTA.setMdnsEnabled(false);

  ArduinoOTA.onStart([]() {
    logInfo("OTA: update starting");
    if (windowOpen) {
      closeWindow();
      windowOpen = false;
    }
    noisePause();
  });
  ArduinoOTA.onProgress([](unsigned int, unsigned int) {
    esp_task_wdt_reset();
  });
  ArduinoOTA.onEnd([]() {
    logInfo("OTA: update written, restarting");
  });
  ArduinoOTA.onError([](ota_error_t error) {
    logInfo("OTA: failed (%u), staying on %s", (unsigned)error, FIRMWARE_VERSION);
    noiseResume();
  });

  ArduinoOTA.begin();
  otaListening = true;
}
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
void loop() {
  esp_task_wdt_reset();
  stationHttpHandle();
  ArduinoOTA.handle();

  reportWifiEvents();
  reportClockStep();
  bool online = ensureWifi();

  if (online) {
    sntpBegin();
  }

  // No reading until the clock is set: the window is unknown without it.
  if (!stationClockIsSet()) {
    if (online) {
      syncClock(NTP_TIMEOUT_MS);
    } else {
      delay(1000);
    }
    return;
  }

  if (lastSampleMs == 0 || millis() - lastSampleMs >= SAMPLE_INTERVAL_MS) {
    lastSampleMs = millis();

    station_reading_t reading;
    if (readSensors(reading)) {
      // Off the reading's own stamp: an SNTP step can cross a slot boundary.
      uint32_t slot = windowSlotOf(reading.timestamp);

      if (windowOpen && slot != window.slot) {
        closeWindow();
        windowOpen = false;
        restartIfStuck();

        lastUploadAttemptMs = 0;
      }

      if (!windowOpen) {
        windowBegin(window, slot);
        windowOpen = true;
      }

      windowAdd(window, reading);
    }
  }

  static uint32_t lastNoiseRetryMs = 0;
  if (millis() - lastNoiseRetryMs >= NOISE_RETRY_MS) {
    lastNoiseRetryMs = millis();
    noiseResume();
  }

  if (online && windowBufferCount() > 0 &&
      (lastUploadAttemptMs == 0 || millis() - lastUploadAttemptMs >= UPLOAD_RETRY_MS)) {
    uploadBuffered();
  }

  delay(100);
}

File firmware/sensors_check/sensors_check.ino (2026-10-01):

// Bench check of all four sensors; a missing one is retried every pass.

#include <Wire.h>
#include <ESP_I2S.h>
#include <driver/gpio.h>
#include <Adafruit_BMP280.h>
#include <Adafruit_SHT4x.h>

// Must match the base board: D21 = SDA, D22 = SCL, D26 = SCK, D25 = WS, D33 = SD.
#define SDA_PIN 21
#define SCL_PIN 22
#define I2S_SCK_PIN 26
#define I2S_WS_PIN 25
#define I2S_SD_PIN 33

#define BMP280_ADDR 0x76
#define VEML7700_ADDR 0x10

// VEML7700 registers, driven raw.
#define VEML7700_REG_CONF 0x00
#define VEML7700_REG_ALS 0x04
#define VEML7700_REG_WHITE 0x05

// Least sensitive setting (gain 1/8, 25 ms): full sun does not saturate (~140 klx).
#define VEML7700_CONF_GAIN_1_8_IT_25MS 0x1300
#define VEML7700_LUX_PER_COUNT 2.1504f
#define VEML7700_IT_MS 25
#define SAMPLE_RATE 16000
#define FRAMES_PER_READ 1024

// The mic is muted for 2^18 SCK cycles after the clock starts: 256 ms at 1.024 MHz.
#define WARMUP_MS 300

#define PASS_MS 2000

// As in the station firmware: the 4 m cable.
#define I2C_CLOCK_HZ 20000

static Adafruit_BMP280 bmp(&Wire);
static Adafruit_SHT4x sht;
static I2SClass i2s;
static int32_t frames[FRAMES_PER_READ * 2];

static bool bmpReady = false;
static bool shtReady = false;
static bool vemlReady = false;
static bool i2sReady = false;

static void scanBus() {
  Serial.print("I2C scan:");

  uint8_t found = 0;
  for (uint8_t addr = 1; addr < 127; addr++) {
    Wire.beginTransmission(addr);
    if (Wire.endTransmission() == 0) {
      Serial.printf(" 0x%02X", addr);
      found++;
    }
  }

  Serial.println(found == 0 ? " nothing" : "  (expect 0x10 VEML7700, 0x44 SHT4x, 0x76 BMP280)");
}

static bool bmpBegin() {
  if (!bmp.begin(BMP280_ADDR)) return false;

  bmp.setSampling(Adafruit_BMP280::MODE_FORCED,
                  Adafruit_BMP280::SAMPLING_X1,
                  Adafruit_BMP280::SAMPLING_X1,
                  Adafruit_BMP280::FILTER_OFF);
  return true;
}

static bool shtBegin() {
  if (!sht.begin(&Wire)) return false;

  sht.setPrecision(SHT4X_HIGH_PRECISION);
  sht.setHeater(SHT4X_NO_HEATER);
  return true;
}

static void reportBmp() {
  if (!bmpReady) bmpReady = bmpBegin();
  if (!bmpReady) {
    Serial.print("BMP280 --- no answer          ");
    return;
  }

  if (!bmp.takeForcedMeasurement()) {
    Serial.print("BMP280 --- measurement failed ");
    bmpReady = false;
    return;
  }

  Serial.printf("BMP280 %6.2f C %7.2f hPa  ", bmp.readTemperature(), bmp.readPressure() / 100.0f);
}

static void reportSht() {
  if (!shtReady) shtReady = shtBegin();
  if (!shtReady) {
    Serial.print("| SHT4x --- no answer         ");
    return;
  }

  sensors_event_t humidity, temp;
  if (!sht.getEvent(&humidity, &temp)) {
    Serial.print("| SHT4x --- read failed       ");
    shtReady = false;
    return;
  }

  Serial.printf("| SHT4x %6.2f C %6.2f %%  ", temp.temperature, humidity.relative_humidity);
}

static bool vemlWrite(uint8_t reg, uint16_t value) {
  Wire.beginTransmission(VEML7700_ADDR);
  Wire.write(reg);
  Wire.write(value & 0xFF);
  Wire.write(value >> 8);
  return Wire.endTransmission() == 0;
}

static bool vemlRead(uint8_t reg, uint16_t& value) {
  Wire.beginTransmission(VEML7700_ADDR);
  Wire.write(reg);
  if (Wire.endTransmission(false) != 0) return false;
  if (Wire.requestFrom(VEML7700_ADDR, 2) != 2) return false;

  value = Wire.read();
  value |= Wire.read() << 8;
  return true;
}

static bool vemlBegin() {
  if (!vemlWrite(VEML7700_REG_CONF, VEML7700_CONF_GAIN_1_8_IT_25MS)) return false;

  delay(VEML7700_IT_MS * 2 + 5);  // power-up plus one integration
  return true;
}

static void reportVeml() {
  if (!vemlReady) vemlReady = vemlBegin();
  if (!vemlReady) {
    Serial.print("| VEML7700 --- no answer      ");
    return;
  }

  uint16_t als, white;
  if (!vemlRead(VEML7700_REG_ALS, als) || !vemlRead(VEML7700_REG_WHITE, white)) {
    Serial.print("| VEML7700 --- read failed    ");
    vemlReady = false;
    return;
  }

  Serial.printf("| VEML7700 %8.1f lx (als %5u white %5u)  ", als * VEML7700_LUX_PER_COUNT, als, white);
}

// Samples are 24-bit, left-aligned in 32. AC rms of one slot, -1 when dead (constant).
static double slotRms(size_t slot, size_t count) {
  int32_t min = INT32_MAX;
  int32_t max = INT32_MIN;
  double sum = 0;

  for (size_t i = 0; i < count; i++) {
    const int32_t v = frames[i * 2 + slot] >> 8;
    if (v < min) min = v;
    if (v > max) max = v;
    sum += v;
  }
  if (min == max) return -1;

  const double mean = sum / count;
  double sq = 0;
  for (size_t i = 0; i < count; i++) {
    const double ac = (frames[i * 2 + slot] >> 8) - mean;
    sq += ac * ac;
  }
  return sqrt(sq / count);
}

static void reportMic() {
  if (!i2sReady) {
    Serial.print("| INMP441 --- I2S driver failed");
    return;
  }

  const size_t got = i2s.readBytes((char*)frames, sizeof(frames));
  const size_t count = got / (2 * sizeof(int32_t));
  if (count == 0) {
    Serial.print("| INMP441 --- no data from driver");
    return;
  }

  const double left = slotRms(0, count);
  const double right = slotRms(1, count);

  if (left >= 0 && right < 0) {
    Serial.printf("| INMP441 %6.1f dBFS", 20.0 * log10(left / 8388608.0));
  } else if (left < 0 && right >= 0) {
    Serial.print("| INMP441 --- data in RIGHT slot, strap L/R to GND");
  } else if (left >= 0 && right >= 0) {
    Serial.print("| INMP441 --- data in both slots, SD is noise (mic not driving it)");
  } else {
    Serial.print("| INMP441 --- all zero, no mic");
  }
}

void setup() {
  Serial.begin(115200);
  delay(1000);  // USB serial attach

  Serial.println();
  Serial.printf("Sensors check - I2C SDA=%d SCL=%d, I2S SCK=%d WS=%d SD=%d\n",
                SDA_PIN, SCL_PIN, I2S_SCK_PIN, I2S_WS_PIN, I2S_SD_PIN);

  Wire.begin(SDA_PIN, SCL_PIN);
  Wire.setClock(I2C_CLOCK_HZ);
  scanBus();

  i2s.setPins(I2S_SCK_PIN, I2S_WS_PIN, -1, I2S_SD_PIN);
  i2sReady = i2s.begin(I2S_MODE_STD, SAMPLE_RATE, I2S_DATA_BIT_WIDTH_32BIT, I2S_SLOT_MODE_STEREO);
  if (i2sReady) {
    // As in the station firmware: weakest drive on the clocks that share the cable with I2C.
    gpio_set_drive_capability((gpio_num_t)I2S_SCK_PIN, GPIO_DRIVE_CAP_0);
    gpio_set_drive_capability((gpio_num_t)I2S_WS_PIN, GPIO_DRIVE_CAP_0);
    delay(WARMUP_MS);
    i2s.readBytes((char*)frames, sizeof(frames));  // drop the muted start
  }
}

void loop() {
  const uint32_t start = millis();

  // I2C only with the mic clocks stopped (noiseHush() in the station firmware).
  if (i2sReady) i2s_channel_disable(i2s.rxChan());
  reportBmp();
  reportSht();
  reportVeml();
  if (i2sReady) {
    i2s_channel_enable(i2s.rxChan());
    delay(WARMUP_MS);
    i2s.readBytes((char*)frames, sizeof(frames));  // drop stale DMA data and the muted start
  }
  reportMic();
  Serial.println();

  const uint32_t spent = millis() - start;
  if (spent < PASS_MS) delay(PASS_MS - spent);
}

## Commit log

2026-09-01 feat(dashboard): add weather station dashboard
    Full-page Livewire component with three full-bleed Flux chart
    strips (temperature, humidity, pressure), giant current-value
    readouts, live scrub summaries, tooltips and dark mode. Data is
    generated in-component as a stand-in for the ESP32 feed (unix
    timestamp + t/h/p every 10 minutes); swap readings() for real
    storage when the backend lands. Czech number/date formatting,
    fonts self-hosted via Bunny.
2026-09-01 feat(dashboard): switch display face and add location map
    Bricolage Grotesque replaces Big Shoulders for the title and the
    readouts: it fills the hero column instead of leaving a narrow
    strip, and the weight now survives Flux's own heading class.
    Title scales fluidly from 56px to 184px.
    Adds a Leaflet strip below the charts marking the reporting area
    as a 500 m circle rather than a pin. Tiles come straight from
    OpenStreetMap - no API key, no billing - desaturated in CSS and
    inverted for dark mode, so the basemap stays quiet behind the
    data colours.
2026-09-01 feat(dashboard): select a range on the temperature chart
    Press, drag and release over CH1 to mark a span of readings. The
    selection reports its bounds, how many readings it covers and
    their min, max and mean; escape, a click or the clear button
    drops it.
    Flux charts scrub on hover but have no range selection, so the
    brush is hand-rolled. It maps pixels to indices off the rendered
    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
2026-09-04 feat(api): add authenticated sensor measurement ingest endpoint
    Adds POST /api/v1/measurement guarded by a bearer token middleware and
    rate limited to 10 requests per minute. Payloads are versioned through
    ProtocolVersion and decoded into a MeasurementData value object, so new
    sensor firmware protocols can be added without touching the stored shape.
2026-09-04 feat(dashboard): read measurements from the database
    The dashboard rendered a month of simulated readings generated in the
    component. It now queries the measurements table for the trailing 31
    days and converts the stored protocol units for display: temperature and
    humidity are hundredths, pressure is pascals.
    Temperature and humidity keep two decimals so the sensor's resolution
    survives to the page; humidity was previously rounded to whole percent.
    An empty table used to be a fatal error, since the summary figures read
    past the end of an empty array. It now renders an empty state instead,
    and the hourly delta falls back to the oldest point when fewer than an
    hour of readings exist.
    Measur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
2026-09-04 feat(firmware): bring the ESP32 sketches into the repo
    The station is two halves of one system and the protocol only makes sense
    read from both sides, so the firmware moves in next to the server it talks
    to. firmware/README.md carries the wiring, the payload contract, and the
    measurement notes that are worth keeping.
    secrets.h is gitignored; secrets.example.h documents what belongs in it.
2026-09-04 feat(api): ping the uptime monitor after storing a batch
    Polling the site only proves the server answers. It says nothing about the
    station, which can go quiet for a dead battery, a WiFi outage, or a wedged
    sensor while the dashboard keeps serving stale readings.
    The endpoint now pings an Uptime Kuma push monitor once a batch is stored.
    The monitor expects a beat within an hour against a ten minute reporting
    interval, so a real outage is unambiguous and a couple of missed uploads are
    not.
    Sent after the response, so the device never waits on the monitor, and
    swallowed on failure, since a missed heartbeat is no reason to fail an upload
    that already landed. SENSOR_HEARTBEAT_URL unset disable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
2026-09-04 docs: replace the framework readme, add licence and badges
    The root readme was still the Laravel skeleton, which said nothing about this
    repo. It now covers what the thing is, how the halves fit together, the API
    contract, and how it is deployed, and leaves the hardware detail to the
    firmware readme rather than repeating it.
    composer.json described the project as "laravel/framework" by its keywords;
    description, keywords, homepage and author now match what this actually is.
    The lock file is regenerated for the new content hash, no package changed.
    LICENSE.md spells out the MIT licence composer.json has always claimed.
2026-09-04 feat(dashboard): credit the author in the footer
    Adds the copyright line and a link to the author's GitHub profile. The year
    comes from the request, so it does not need touching every January.
    The protocol note next to it moves behind the sm breakpoint: three blocks
    wrap to three lines on a phone, and that one describes the wire format rather
    than the page.
2026-09-04 ci: keep tests/Unit in the repo so paratest can find it
    The directory is empty, git does not track empty directories, and paratest
    refuses to start when a testsuite in phpunit.xml points at a path that does
    not exist: "Test directory tests/Unit not found". The plain runner tolerates
    it, which is why this only broke once CI ran the suite with --parallel, and
    why it passed locally where the directory is on disk.
2026-09-04 feat(seeder): seed from real observations for the station's location
    The seeder drew every field independently across the whole protocol range, so
    a chart of it was a band of noise. Replacing that with a synthetic weather
    model made it look plausible and stay wrong: it centred pressure on 1013 hPa,
    which is sea level, while a BME280 at 345 m reads about 977. Every row was
    36 hPa off, and nothing about a smooth curve gives that away.
    So the values now come from real hourly observations for Plzen-Slovany
    (Open-Meteo reanalysis, 744 points, exactly 31 days). The seeder interpolates
    them to the ten minute reporting interval and jitters them by hundredths, so
    consecutive readings differ the way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
2026-09-04 fix(dashboard): label readings in Czech local time
    Stored stamps are UTC epochs and the app clock stays on UTC, but the
    station sits in Plzeň, so every label was reading two hours early in
    summer.
    The zone cannot be passed through `:format`. Flux builds its date
    formatters as `{...format, timeZone: 'UTC'}` in all three places that
    render a stamp - axis tick, tooltip heading and summary - spreading the
    caller's options first, so a `timeZone` of our own is overwritten every
    time. Shifting the instant to the Prague wall clock and tagging it `Z`
    is what makes those formatters print local time.
    That makes `d` a wall-clock reading rather than a real instant, so it
    must be shifted once and never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
2026-09-04 chore: migrate the build to Vite Plus
    `vp migrate` moved the config onto `defineConfig` from vite-plus, wrapped
    the plugins in `lazyPlugins`, and added its own formatting, linting and
    staged-file checks. The generated hook runner under `.vite-hooks/_` is
    rebuilt by `vp config` on install, so only the hook itself is tracked.
    It also pinned `devEngines.packageManager` to the npm it resolved rather
    than the one installed, which locks out every npm command until the two
    agree - the version that satisfies it ships with Node 24.
    fontaine comes along because the fonts plugin asks for it by name: without
    it the size-adjusted fallback faces are skipped, and the hero heading is
    large enough that swa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
2026-09-04 ci: install the npm that Vite Plus pins
    Bumping the Node version was not enough: Node 24 bundles npm 11, and the
    pin asks for 12.0.2, so `npm ci` still failed before installing anything.
    Verified against a clean clone on Node 24.20.0, where its bundled npm
    11.19.0 refuses to run.
    The step runs from the runner's temp directory because npm applies the same
    check to itself, and would block its own upgrade inside the project.
2026-09-04 chore: drop the npm pin and pin the runtime instead
    `vp migrate` wrote devEngines.packageManager to keep a team on one npm.
    There is no team here, and the pin cost more than it gave: npm refuses to
    run at all while the installed version disagrees, so it broke every npm
    command locally and needed a step in CI to install the version it asked
    for.
    A pinned runtime covers the same ground without the failure mode, so
    .node-version records Node 24 for both the local version manager and CI.
    Verified end to end on a clean clone running Node 24.20.0 with its own
    npm 11.19.0: install, build, Pint, Rector, PHPStan and the suite all pass.
    Vite+ writes that field only from its migration and bootstrap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
2026-09-05 fix: stop the station's clock drifting away from the server
    The station's readings were arriving stamped four minutes ahead of the
    server that stores them, and the dashboard duly reported the last
    transmission as "4 minutes from now".
    syncNtp() returned early whenever the clock merely looked set, which after
    the first cold boot is always. From then on the clock free-ran on the RTC
    oscillator through every deep sleep - an internal RC circuit accurate to
    within a few percent, so minutes of drift a week. It now re-syncs once the
    last answer is six hours old, and waits on the SNTP completion flag rather
    than on the clock looking plausible, which on a re-sync it already does.
    A timed-out sync n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
    [weather_station.ino]
2026-09-05 fix(firmware): sync the clock hourly
    Six hours was my own pick and never the ask. The radio is already up for the
    upload, so one sync an hour is one wakeup in six and a fraction of a second
    awake, which holds the drift to about a second instead of tens of them.
    [weather_station.ino]
2026-09-05 feat(firmware): report each wakeup on the on-board LED
    Three short blinks once the server has accepted the upload, five long ones
    for any fault - sensor, WiFi, clock or upload. The length carries the
    distinction; the count only separates the two, because counting five long
    blinks across a room is not something anyone does reliably.
    A fault outranks a delivery. Buffered readings still reach the server while
    the sensor is dead, and a station in that state is not working.
    The blink is blocking and runs immediately before deep sleep, which
    subtracts the time spent awake, so the ten-minute cadence is unaffected.
    [weather_station.ino]
2026-09-05 feat(firmware): signal only a delivered upload
    Drops the fault blink added a commit ago. It would have fired on every
    wakeup for as long as a fault lasted, and the station sleeps ten minutes
    between them - so seeing one means standing over the device, by which point
    the serial log says more. On a battery board that is several seconds of
    awake time every cycle, spent on nobody.
    What remains is three short blinks once the server has accepted the upload
    and the buffer has been cleared. The dashboard and the heartbeat monitor
    report a station that has gone quiet.
    [weather_station.ino]
2026-09-05 feat(firmware): log signal strength, and what is audible when it fails
    "WiFi failed" cannot separate a wrong password from a site the AP does not
    reach, which is the question when a board that works indoors stops working
    three metres away. Every successful association now reports its RSSI, and a
    failed one scans and lists what the radio can hear, marking our own network.
    Around -70 dBm is comfortable and -80 marginal; past -85 an association may
    still form but will not survive a TLS upload.
    [weather_station.ino]
2026-09-07 feat(firmware): blink at power-up and on the first upload only
    The confirmation fired on every delivery, which after the first one is the
    LED blinking at nobody: the station sleeps ten minutes between them, so
    seeing one means standing over the device.
    What remains is what you actually watch for while setting it up - the board
    came up, and the link works. A flag in RTC memory spends the delivery blink
    once per power cycle, reset on a cold boot because RTC memory holds garbage
    after a power loss.
    [weather_station.ino]
2026-09-08 feat(dashboard): list the last three transmissions and poll for them
    The tail prints each packet in the units the station sent it in, read across
    the whole table so that zooming into last spring cannot empty it.
    A sixty second poll rather than a broadcast: one upload per ten minutes does
    not pay for a websocket server. A zoomed window is a pair of fixed epochs, so
    the re-query returns the same rows and the payload attribute morphs back
    identical, which leaves the canvases untouched. The navigator watches its own
    rows instead, because it alone always spans the whole record.
    The page is called Station Log now, the trend figures take their channel's
    colour, and the link indicator breathes whi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
2026-09-08 feat(UI): draw the station mark as the favicon
    Three channel traces on the panel ground, in the sizes browsers ask for. The
    .ico replaces the empty file Laravel ships.
2026-09-08 build(docker): multi-stage image to replace the nixpacks build
    Nixpacks ships the whole Nix toolchain and both dependency trees in the
    runtime image, 2.63GB of which the app needs about 65MB. Composer and npm
    now run in throwaway stages and only vendor/ and public/build/ carry over:
    297MB.
2026-09-09 feat(firmware): move the station to a FireBeetle 2 ESP32-C6
    Pins come from the board variant now instead of the DevKit numbers. The C6
    has no USB-serial chip, so the port only exists while the board is awake:
    a cold boot waits for a monitor to attach and Serial never blocks a wakeup.
2026-09-09 feat(firmware): full TX power and no modem sleep on the uplink
2026-09-09 fix(dashboard): move the station circle onto the sensor
2026-09-09 feat(dashboard): reduce station pressure to sea level
    The BME280 hangs at 345 m, so its readings sit some 40 hPa under what a
    forecast quotes and could not be compared against one. The record keeps
    station pressure; the reduction happens on the way to the page.
2026-09-09 feat(dashboard): pair temperature and humidity on one chart strip
    Two channels that run against each other read better on one grid, and
    that leaves room to lift the navigator above the strips it scrolls -
    below them a drag moved a chart that had scrolled off the screen. The
    payload tail follows the charts as a footnote to them.
2026-09-09 fix(dashboard): thin the navigator by bucket, not by epoch phase
    The station stamps an upload when it wakes, so its timestamps sit a
    couple of minutes off the slot and a record shorter than one six-hour
    bucket holds no row the modulo window can find. Production ran a few
    hours old and the navigator had nothing to draw.
2026-09-09 fix(dashboard): thin the window by bucket too
    Same trap as the navigator: a station stamping its uploads more than a
    step off the slot would leave the modulo window empty and the chart with
    nothing to draw. Both paths now share firstPerBucket().
2026-09-09 fix(dashboard): plot pressure at the sensor's own resolution
    The strip's axis scales to the window, and a day of weather is a couple
    of hPa, so rounding to tenths drew the line as a staircase. Whole pascals
    are what the BME280 reports. The readouts still print a tenth.
2026-09-09 refactor(dashboard): rename last transmission to last measurement
    It reads MAX(timestamp), which is when the station read its sensor, not
    when anything reached the server.
2026-09-09 fix(dashboard): date the payload tail by arrival, not by the reading
    The reading's own stamp is printed in the JSON beside it, so the date
    repeated it. created_at is the other half: a batch buffered through a
    lost link lands minutes or hours after it was measured.
2026-09-12 feat(dashboard): dew point line with switchable strip channels
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2026-09-15 feat(dashboard): average readings into fixed slots, cap the window at a month
2026-09-16 feat(dashboard): band each line with the extremes of its samples
2026-09-16 feat(firmware): ESP32-C3 on mains, half-minute samples into V2 windows
2026-09-17 fix(firmware): start the HTTP server after the network stack is up
    [weather_station.ino]
2026-09-17 fix(firmware): log the driver's disconnect reason, fail over after a minute
    [weather_station.ino]
2026-09-18 feat(firmware): measure the clock drift at each SNTP re-sync
    [weather_station.ino]
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2026-09-23 feat(firmware): WROOM-32 with SHT41, BMP280 and noise
    [noise.cpp, noise.h, reading_types.h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]
2026-09-23 fix(dashboard): print the noise object in the packet list
2026-09-23 fix(firmware): free the noise buffers for TLS, run I2C at 20 kHz
    [noise.cpp, noise.h, weather_station.ino]
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2026-09-23 fix(firmware): give the mic buffers back when it fails to start
    [noise.cpp, noise.h, weather_station.ino]
2026-09-23 docs: current sensors, noise strips and the mic's upload pause
2026-09-24 feat(dashboard): fold strips and the payload tail
    Units, local time and the window move into value objects, the bucket
    queries into app/Queries.
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2026-09-24 feat(dashboard): zoom by a sideways finger drag on touch screens
2026-09-25 fix(dashboard): keep one forecast accuracy cache row per sensor
2026-09-25 docs(hardware): station schematics and shield hub soldering layout
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2026-09-26 fix(dashboard): outline the waterfall's slot column instead of a crosshair line
2026-09-26 feat(forecast): FORECAST_HISTORY_SINCE to cut what the correction learns from
2026-09-26 docs(forecast): correction 2, its history cut-off and version
2026-09-26 fix(forecast): cut only the correction's history, not the base models'
    An unparseable FORECAST_HISTORY_SINCE is reported and ignored.
2026-09-29 feat(dashboard): show live readings and the sensor in the sky
2026-09-29 feat(dashboard): label the forecast curve with a temperature axis
2026-09-29 docs(hardware): flip the shield hub mic, port facing out
    Header rows swap, so WS and 3V3 reach the mic through wire links and R5 moves to a diagonal under it. C1 dropped; the modules decouple locally.
2026-09-29 docs(hardware): KiCad project for the shield hub
    Schematic, board, footprints and STEP models all come from the generate_*.py scripts.
    [C2_10u_approx.step, INMP441_Round_approx.step, R5_47R_approx.step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]
2026-09-30 feat(firmware): VEML7700 in sensors_check, mic clocks stopped for I2C
2026-09-30 fix(firmware): stop the mic clocks for every sensor read
    [noise.cpp, noise.h, weather_station.ino]
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2026-09-30 perf(database): partial indexes for noise and light per sensor
2026-09-30 docs(hardware): KiCad schematic of the whole station
    [WeatherStation.kicad_sch]
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2026-09-30 docs(hardware): KiCad project for the ESP32 base board
    [BMP280_Module_approx.step, BaseBoard.kicad_pcb, BaseBoard.kicad_sch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]
2026-09-30 docs(hardware): station takes 5 V on VIN through the base board
    [WeatherStation.kicad_sch]
2026-09-30 docs(firmware): link the base board, drain grounded at the ESP32 end
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2026-10-01 test: aggregate every protocol version in the bucket queries
2026-10-01 feat(charts): fold each transmission's JSON behind a button, pretty-printed
2026-10-01 style(UI): drop space before °C in hero temperature delta
2026-10-01 Revert "style(UI): drop space before °C in hero temperature delta"
    This reverts commit 4e430a6c5e9a35860f2c6c84440fe2e6dff51945.
2026-10-03 chore(seed): seed a forecast on every ten-minute slot
2026-10-03 feat(forecast): light-gated temperature correction as an experiment endpoint
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2026-10-05 feat(forecast): period switch and base line on the hour-of-day chart, today as a trace
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2026-10-07 feat(forecast): send the light fit temperature extremes and history start
    Issue the experiment without illuminance; fit through the window's newest reading.
2026-10-07 feat(forecast): light-v5 learns the base model's daytime miss from the temperature swing
2026-10-10 feat(forecast): model race picks the shown temperature per part of the day
2026-10-15 refactor: retire forecasting and refocus on temperature measurement
    Remove the forecast UI, Python service, model scoring and Open-Meteo integration.
    Update site copy and documentation for temperature correction against ČHMÚ Plzeň-Mikulka.
    Drop the forecasts table with migration rollback support and adjust sample pressure to the balcony altitude.
2026-10-15 feat: add calibrated radiation shield temperature correction
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2026-10-15 fix(import): treat a missing current-day reference file as not yet published
2026-10-15 fix(calibration): start shield filters from zero after a data gap
2026-10-15 fix(calibration): respect station events, sun-facing limits, stricter acceptance, 71.8° wall
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2026-10-15 feat(kicad): SPS30 UART header on the base board, runs as solder bridges
2026-10-15 fix(import): pull reference temperatures every 10 minutes
2026-10-15 fix(kicad): solder side row letters run top-down
2026-10-15 fix(kicad): crop solder side render to the board
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2026-10-20 refactor(calibration): one place for the span each calibration corrects
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2026-11-06 feat(calibration): fit shield model v2 against a shade reference
    Mikulka shifted by the balcony's own offset, read in shade before and
    after the morning sun. Low-sun and wind (25 Hz) terms; ties within
    0.02 °C and sunless validation days no longer reject a retrain.
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

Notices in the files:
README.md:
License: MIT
